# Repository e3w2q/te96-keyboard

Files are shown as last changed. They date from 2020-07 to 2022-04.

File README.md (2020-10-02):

# te96




Expandable keyboard PCB with a smaller pitch.

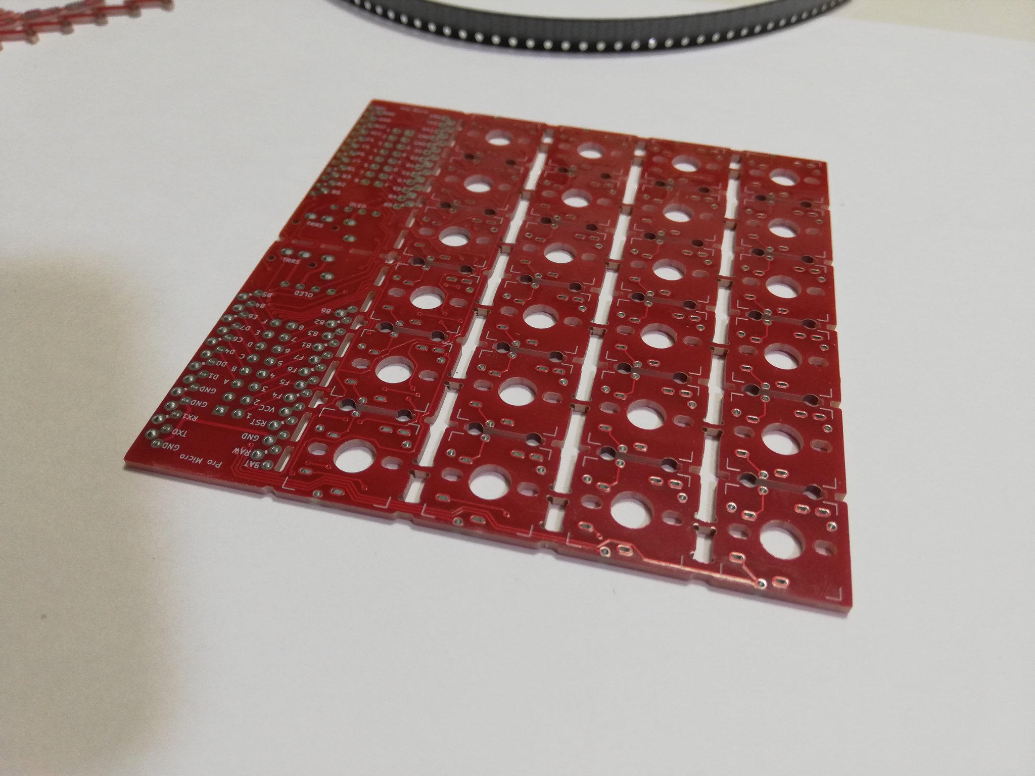
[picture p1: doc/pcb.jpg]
main image


## What is the te96?

The te96 is a keyboard board that can be assembled and expanded in the same way as the [SU120](https://github.com/e3w2q/su120-keyboard), but with a smaller pitch.

I designed the PCB to make it easy to trial and error a smaller pitch keyboard layout.

You may make Row-Staggered, Column-Staggerd, Ortholinear layouts keyboard.

The "te"(手) is named after the Japanese word for 手助け(help) and 手に馴染む(comfort).

## Why open source?

Anyone interested in keyboard could try the keyboard layout more easily.

## Link

[Hardware data (PCB)](pcb/)

[PCBの入手方法](doc/common/pcb_order_guide_jp.md)

[Firmware](https://github.com/e3w2q/qmk_firmware/tree/e3w2q/keyboards/e3w2q/te96)

[自由なレイアウトを作成するには](doc/custom_layout/readme_jp.md)

## Example

### 24 Key Keypad

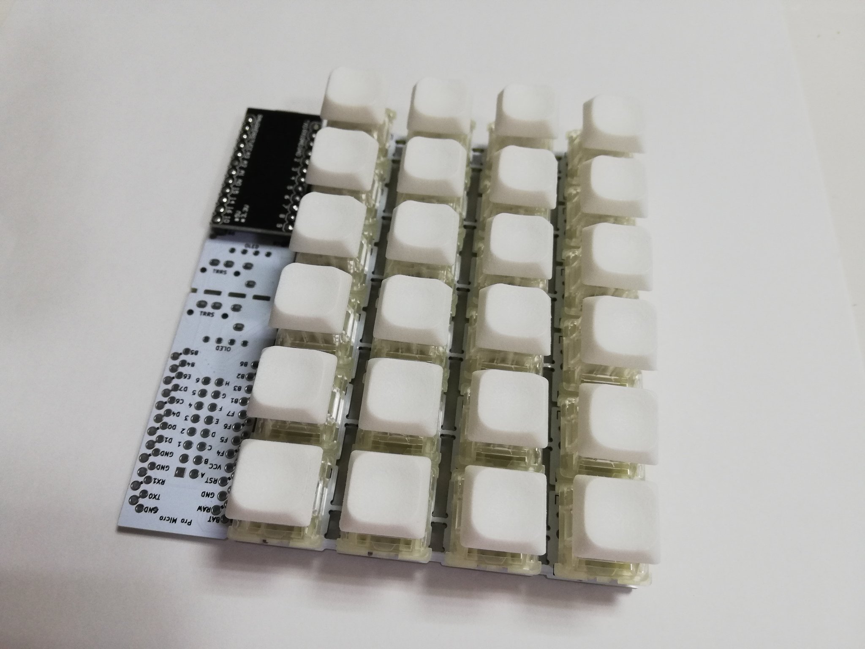
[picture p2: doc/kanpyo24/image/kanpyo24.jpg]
kanpyo24


[ビルドガイド](doc/kanpyo24/readme_jp.md)

### Row-Staggered Keyboard

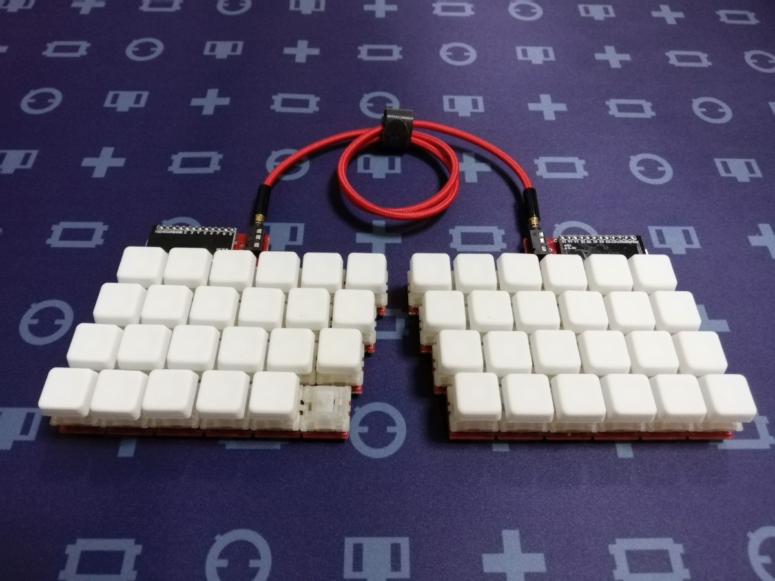
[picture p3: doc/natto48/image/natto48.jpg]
natto48


[ビルドガイド](doc/natto48/readme_jp.md)

### Column-Staggerd Keyboard

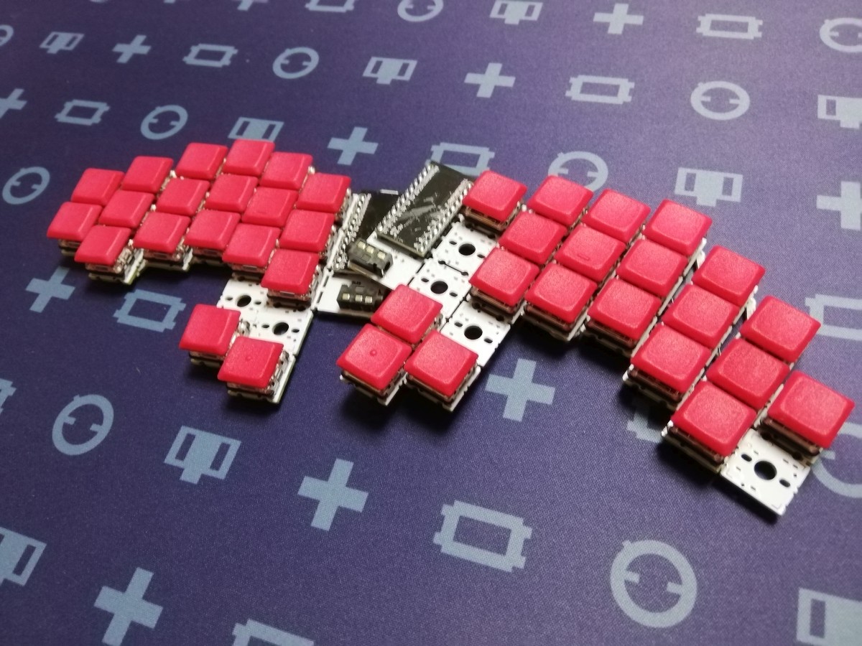
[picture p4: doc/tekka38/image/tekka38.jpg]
tekka38


[ビルドガイド](doc/tekka38/readme_jp.md)

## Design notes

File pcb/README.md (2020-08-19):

# te96 PCB Data

## Schematic
[Schematic PDF](../doc/te96.pdf?raw=true)
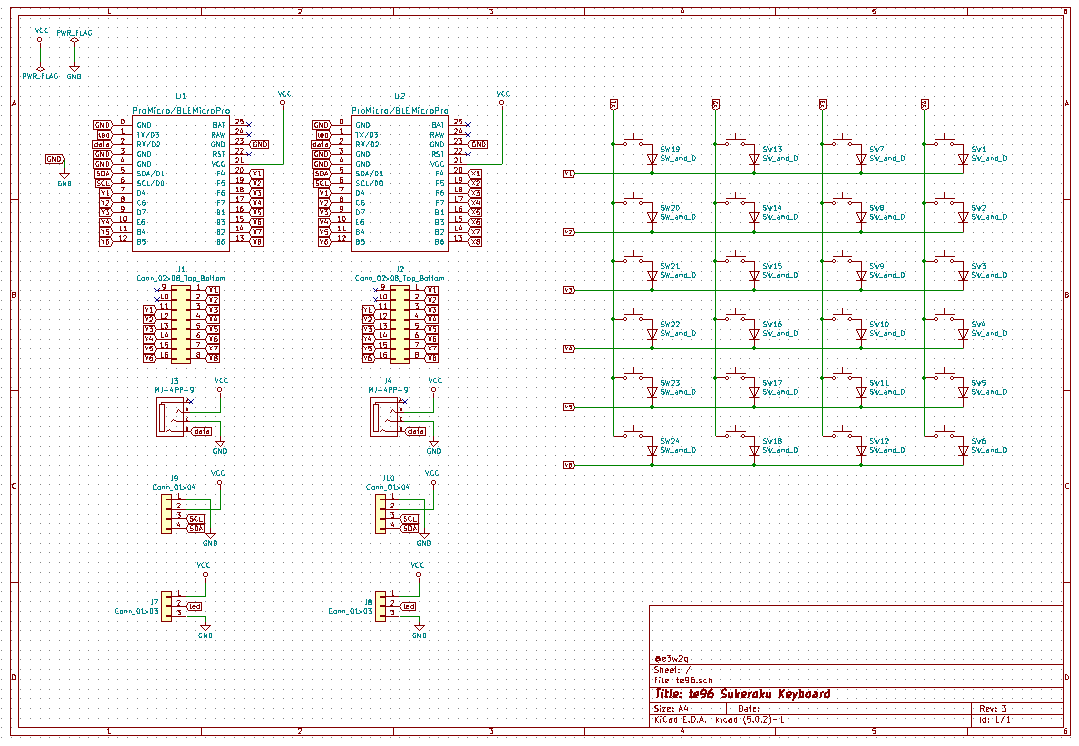
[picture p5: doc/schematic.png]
Schematic


## PCB Layout
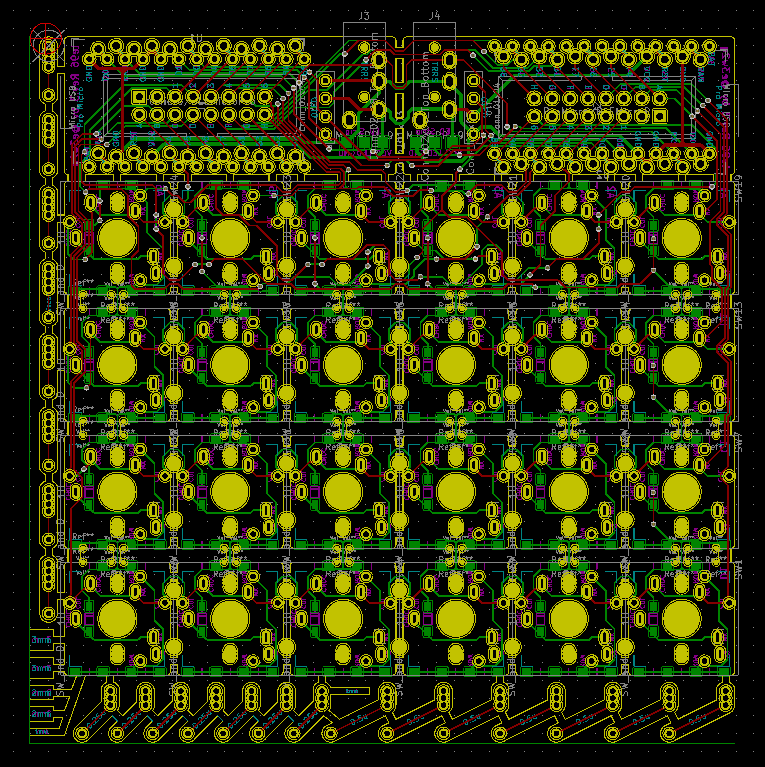
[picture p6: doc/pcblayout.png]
PCB Layout


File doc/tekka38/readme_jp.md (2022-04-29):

# Column-Staggered Keyboard

tekka38

縦16mmキーピッチ、横は16～18mmキーピッチのColumn-Staggerdキーボード（縦方向にズレたキーボード）の作例です。

<!-- TOC -->

- [Column-Staggered Keyboard](#column-staggered-keyboard)
    - [必要なパーツ](#必要なパーツ)
    - [使用する道具、消耗品](#使用する道具消耗品)
    - [ビルドガイド](#ビルドガイド)
        - [Pro Microのもげ防止加工](#pro-microのもげ防止加工)
        - [基板のカット](#基板のカット)
        - [基板側面のヤスリがけ](#基板側面のヤスリがけ)
        - [はんだ付けのイメージトレーニング](#はんだ付けのイメージトレーニング)
        - [カットした基板の結合](#カットした基板の結合)
        - [隣り合う場所の配線](#隣り合う場所の配線)
        - [ダイオードの取り付け](#ダイオードの取り付け)
        - [Pro Microの取り付け（Pro Micro付属のピンヘッダを使う場合）](#pro-microの取り付けpro-micro付属のピンヘッダを使う場合)
        - [Pro Microの取り付け（コンスルーピンヘッダを使う場合）](#pro-microの取り付けコンスルーピンヘッダを使う場合)
        - [TRRSコネクタの取り付け](#trrsコネクタの取り付け)
        - [キースイッチの取り付け](#キースイッチの取り付け)
        - [離れている場所の配線](#離れている場所の配線)
        - [キーキャップの取り付け](#キーキャップの取り付け)
        - [ゴム足の取り付け](#ゴム足の取り付け)
        - [ファームウェアの書き込み](#ファームウェアの書き込み)
    - [トラブルシューティング](#トラブルシューティング)

<!-- /TOC -->

## 必要なパーツ

[te96 パーツリスト](../common/bom_list_jp.md)をご覧ください。

te96基板は3枚使用します。

## 使用する道具、消耗品

[使用する道具、消耗品](../common/tool_guide_jp.md)におすすめの道具類、注意事項等をまとめましたのでご覧ください。

## ビルドガイド

### Pro Microのもげ防止加工

Pro Microにエポキシ接着剤を盛って、簡単にはもげないようにします。

参考1:[ProMicroのモゲ防止ついでにQMK_Firmwareを書き込む - Qiita](https://qiita.com/hdbx/items/2f3e4ddfcadda2a5578e)
参考2:[もげ予防 - Self-Made Keyboards in Japan](https://scrapbox.io/self-made-kbds-ja/%E3%82%82%E3%81%92%E4%BA%88%E9%98%B2)

エポキシ接着剤の2液を混ぜます。

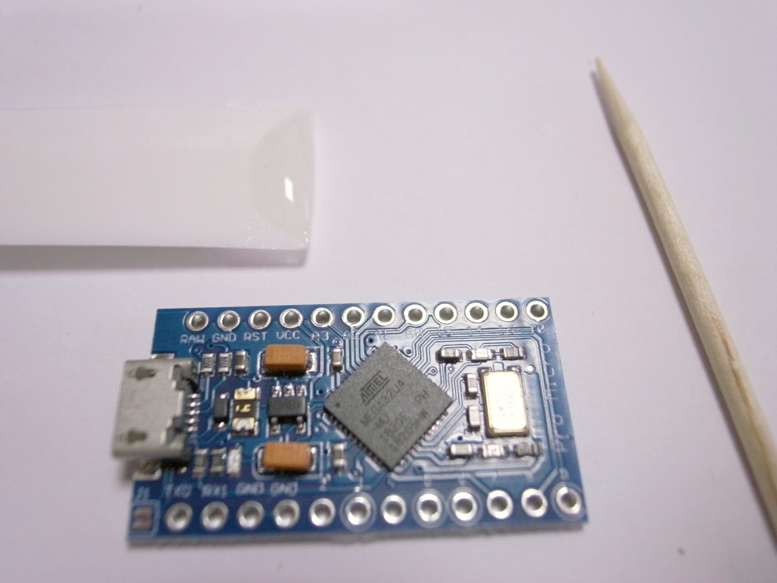
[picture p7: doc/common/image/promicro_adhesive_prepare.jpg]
adhesive_prepare


接着剤を付け始める前にMicro USBコネクタを横から見てください。側面に穴が開いています。この穴に接着剤が入ると端子が入らなくなったり、入りにくくなったりします。

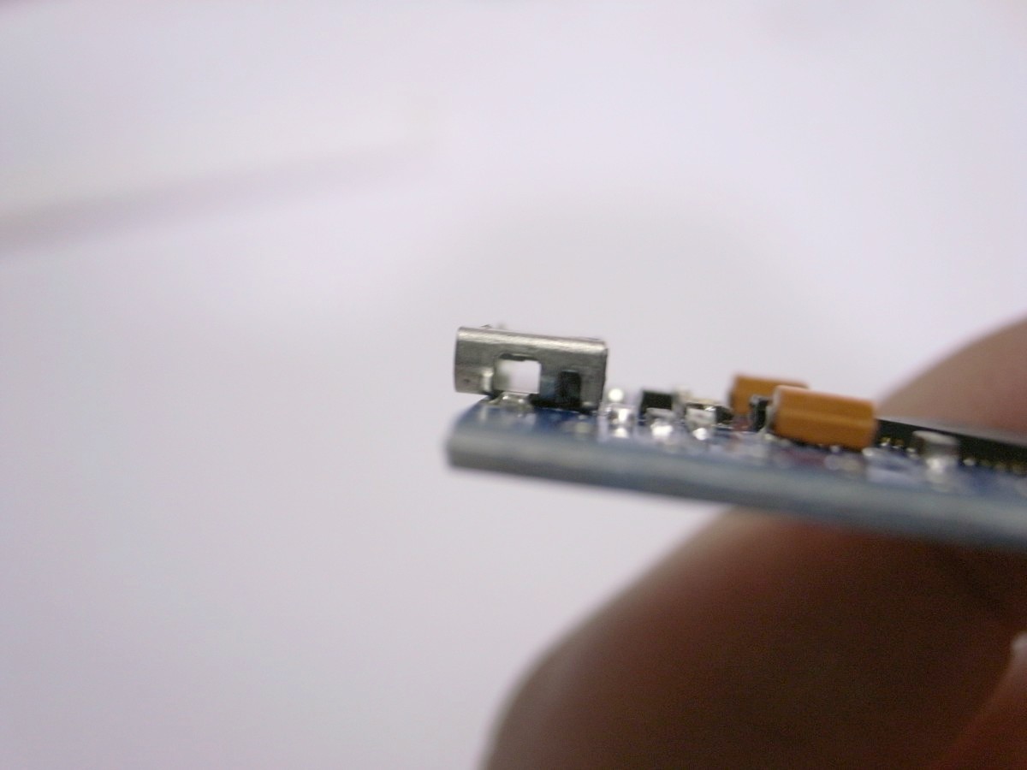
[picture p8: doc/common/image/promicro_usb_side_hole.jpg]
usb_side_hole


この穴を避けて、つまようじなどで接着剤を盛っていきます。

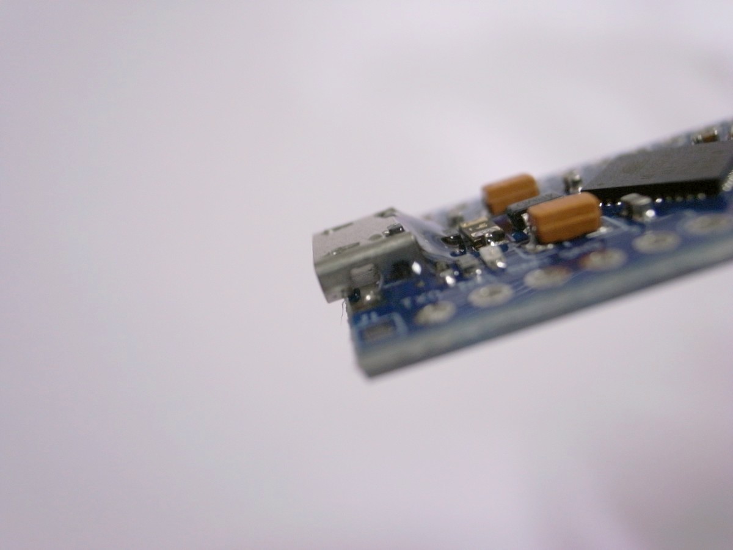
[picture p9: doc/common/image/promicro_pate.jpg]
promicro_pate


乾くまで置いておきます。

### 基板のカット

下の図のように、ニッパーで切っていきます。ニッパーで表裏に切れ目を入れてから手で折り割ってください。

Pro Micro部は左右のどちらを残しても動きます。分割キーボードでPro Micro部を左右対称にしたい場合は注意してください。

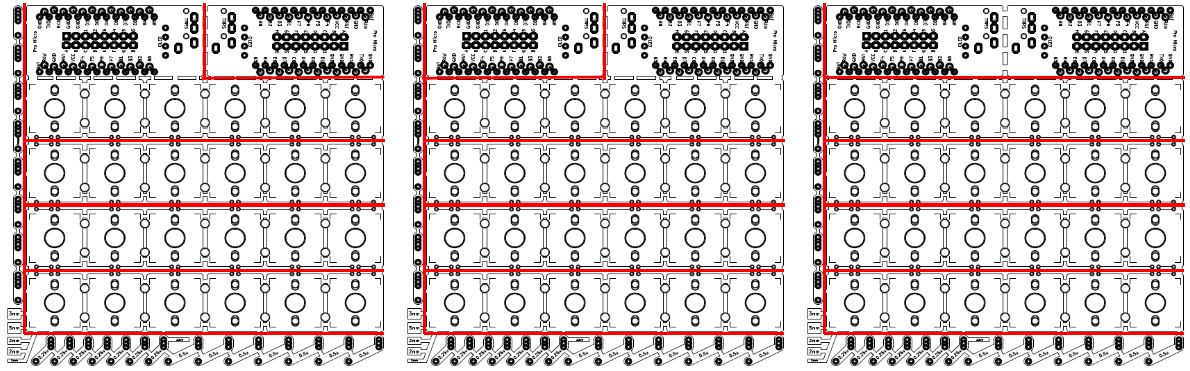
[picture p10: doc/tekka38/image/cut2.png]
cut2


基板を並べてみて、自分の手に合ったちょうどよいズレ方を探します。縦方向のズレは

- ズレなし
- 0.25Uズレ
- 0.5Uズレ

を選べます。

各列の隙間は、

- 隙間なし（16mmキーピッチ）
- 1mm隙間あり（17mmキーピッチ）
- 2mm隙間あり（18mmキーピッチ）

を選べます。

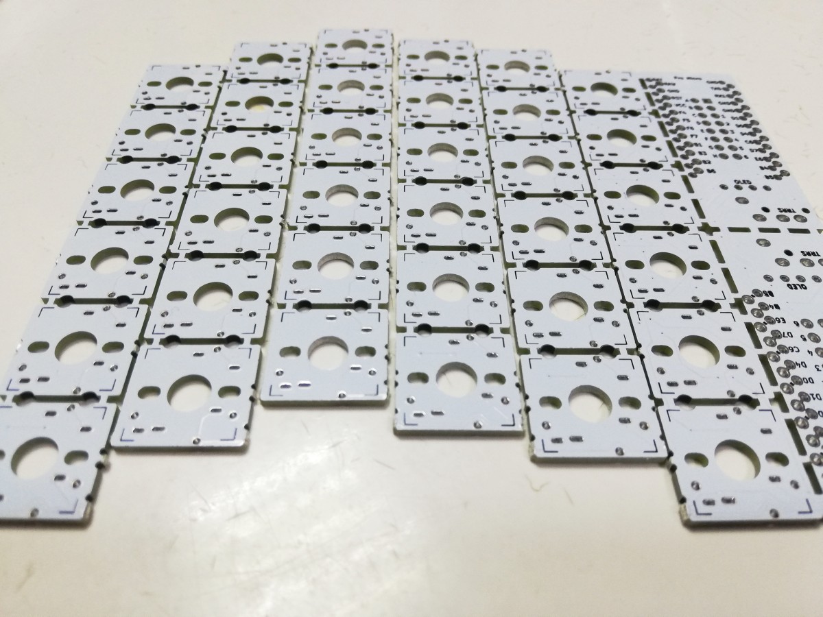
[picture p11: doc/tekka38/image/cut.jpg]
cut


使わない部分をカットします。

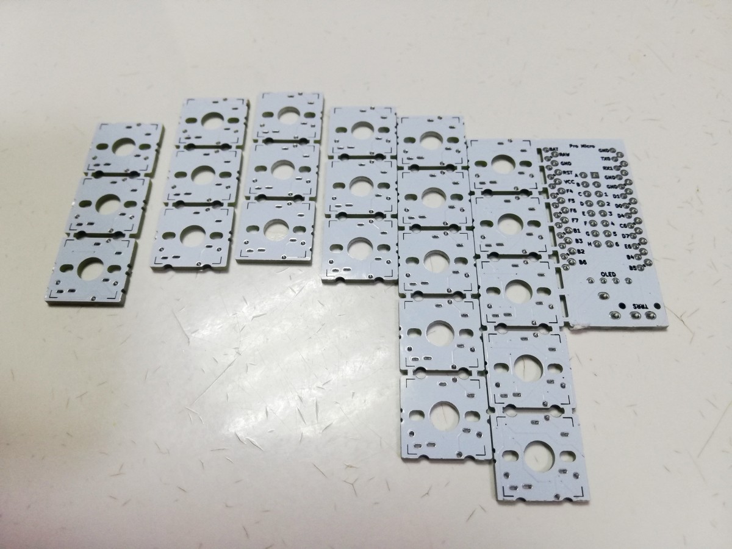
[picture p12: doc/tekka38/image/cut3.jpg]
cut3


### 基板側面のヤスリがけ

机に紙ヤスリを置き、その上で基板のバリがある側面をヤスリがけします。粗目だけでも結構きれいになります。お好みで細目までかけてもよいです。

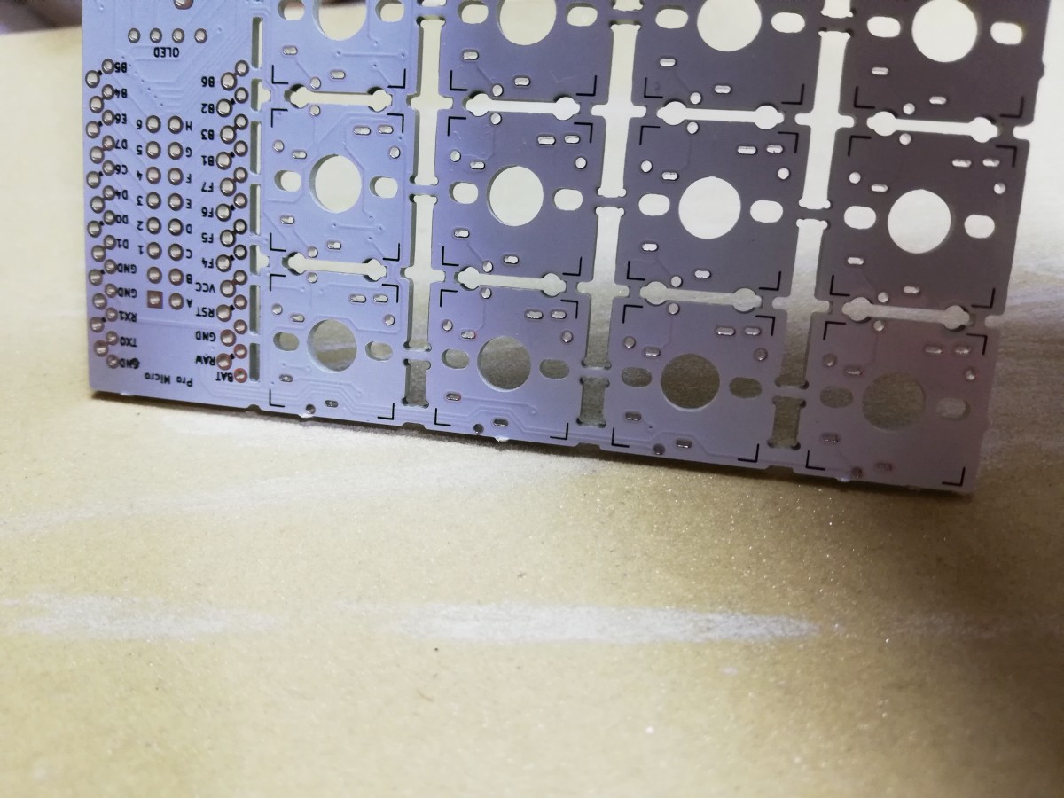
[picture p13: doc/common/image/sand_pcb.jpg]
sand_pcb


### はんだ付けのイメージトレーニング

はんだ付けに慣れている方は次の項に進んでください。

全くはんだ付けをしたことがなかったり、数年ぶりにはんだ付けをする場合は、以下の動画が参考になります。

- [はんだ付けの詳細.m2p - YouTube](https://www.youtube.com/watch?v=ZA-ehWjRfYM)

- [チップ抵抗のはんだ付けと、はんだ量の調整（体験用基板を使用） - YouTube](https://www.youtube.com/watch?v=vqKKElJ1vw0)

- [基礎からわかる！自キ入門講座 第8回「自作キーボードのつくりかた #2」 - YouTube](https://www.youtube.com/watch?v=LOC53FeU-QM&t=999)

### カットした基板の結合

まず**カットした基板を表側にして完成形に並べてからマスキングテープで仮止めしておいてください**。これをせずに進めて、表に向けたときに想定したずらし方と逆になっていたことがありました。

基板を裏返し、ビスケットで結合していきます。ビスケットは3種類あります。下の写真の左から

- 0.5uずらして接続する用
- 0.25uずらして接続する用
- ずらさずに接続する用

です。

縦に連なっている穴は下から

- 16mmキーピッチ用
- 17mmキーピッチ用
- 18mmキーピッチ用
- 19mmキーピッチ用（ずらさずに接続する用のみ）

です。

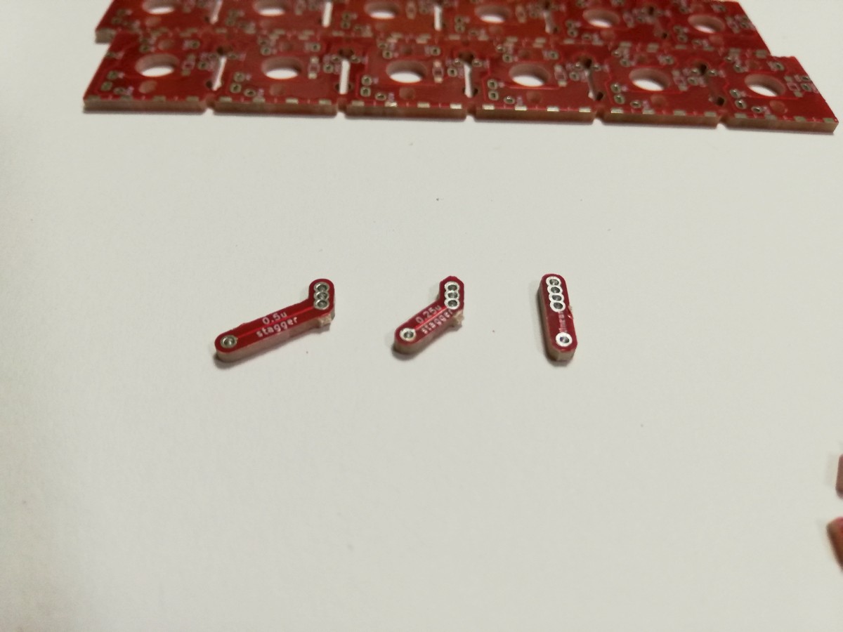
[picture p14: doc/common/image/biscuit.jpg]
biscuit


基板を裏返してビスケットで接続していきます。ビスケットの数が限られているので、下の写真のように、基本的には各列2個のビスケットを使って接続します。ビスケットの数に余裕があればもっと使っても構いません。

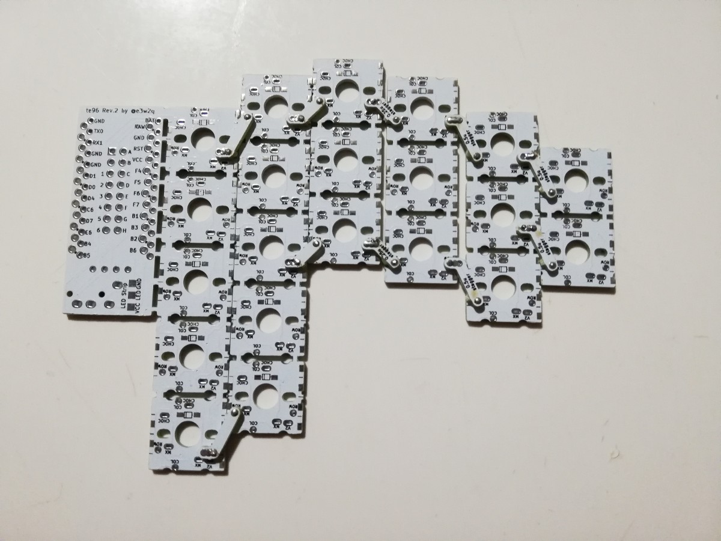
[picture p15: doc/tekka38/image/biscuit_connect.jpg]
biscuit_connect


基板の`ROW`と書かれている穴にビスケットを重ねて、ビンヘッダを差し込みます。

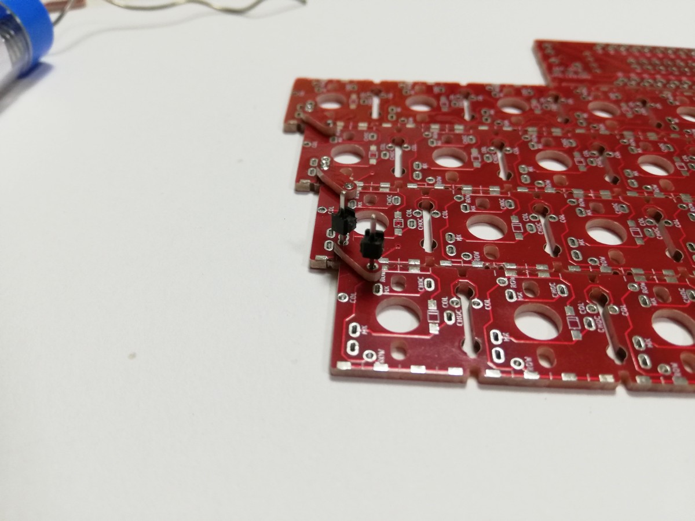
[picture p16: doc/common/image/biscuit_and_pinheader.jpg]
biscuit_and_pinheader


ビスケットからはみ出しているピンヘッダをニッパーでカットして、穴の上からハンダを流し込みます。

16mmキーピッチで接続する場合は基板と基板をくっつけてビスケットで接続すればよいのですが、1mm間隔を空けて17mmキーピッチにしたい場合は、基板に付属の1mmスペーサーをニッパーで切って基板の間に挟んで間隔を空けてください。

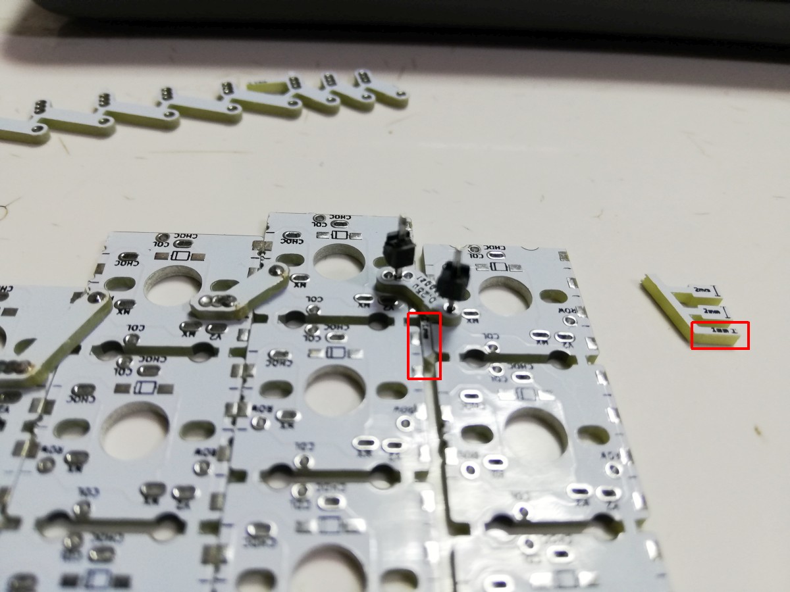
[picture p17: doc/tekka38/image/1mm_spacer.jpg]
1mm_spacer


2mm間隔を空けて18mmキーピッチとしたい場合、同様に基板に付属の2mmスペーサーを使ってください。

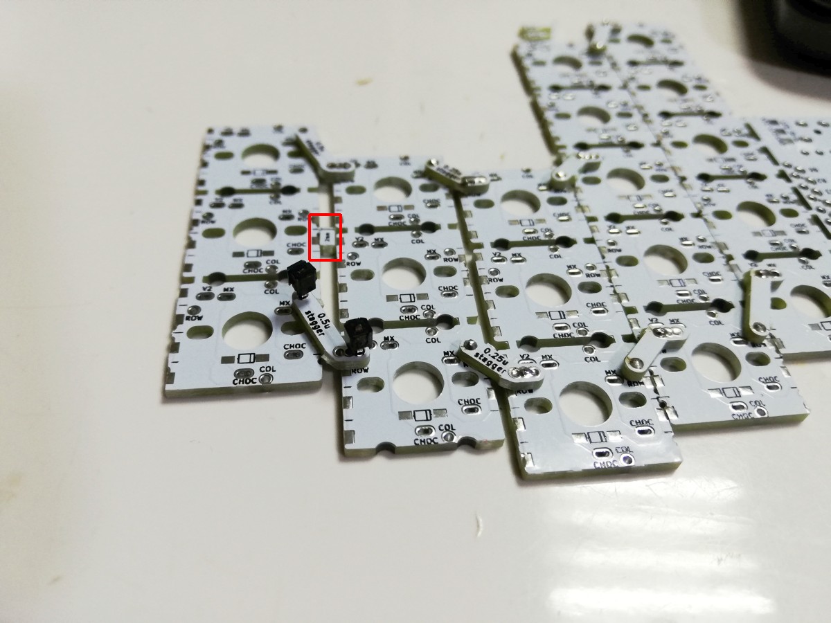
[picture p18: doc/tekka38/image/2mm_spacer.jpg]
2mm_spacer


上下で間隔を変えて、扇形のようにすることも可能です。

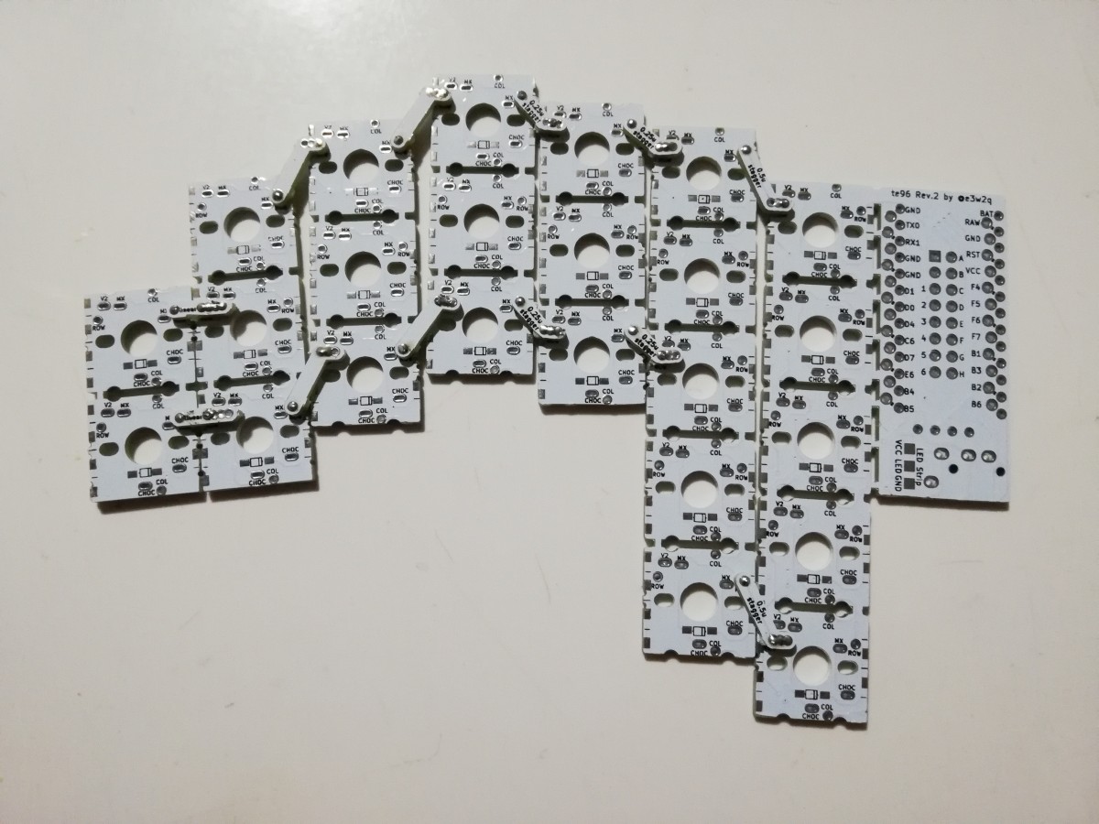
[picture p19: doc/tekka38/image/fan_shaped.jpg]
fan_shaped


### 隣り合う場所の配線

下の写真の赤線のように、ビスケットで接続していない部分の`ROW`と`ROW`をハンダめっき線またはダイオードの切れ端などで配線し、ハンダ付けします。

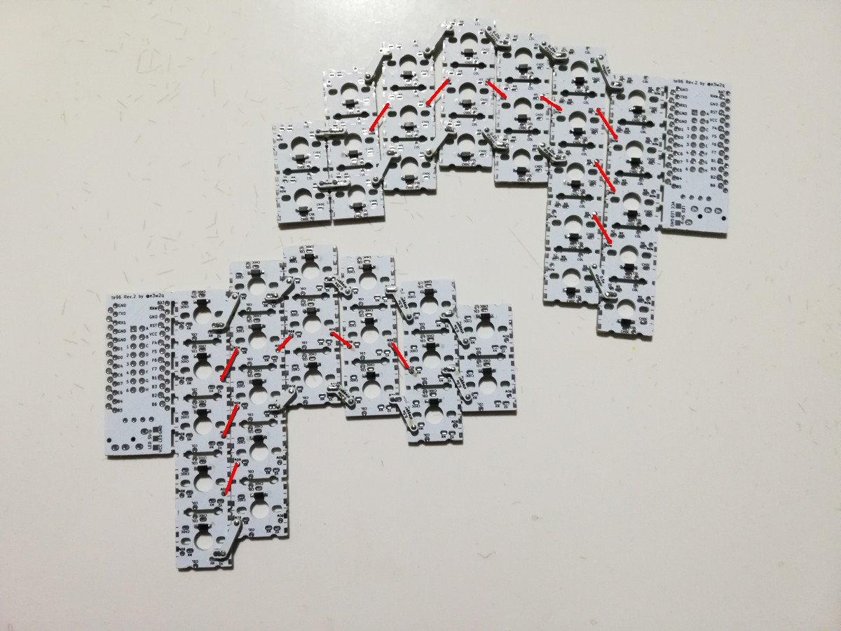
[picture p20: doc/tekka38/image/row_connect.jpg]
row_connect


### ダイオードの取り付け

基板裏側にキースイッチの数だけダイオードを取り付けます。

キースイッチの枠が描いてあるほうが基板の表で、ダイオードの印が描いてあるほうが裏です。

まず片方のパッド上にはんだを溶かして盛ります。

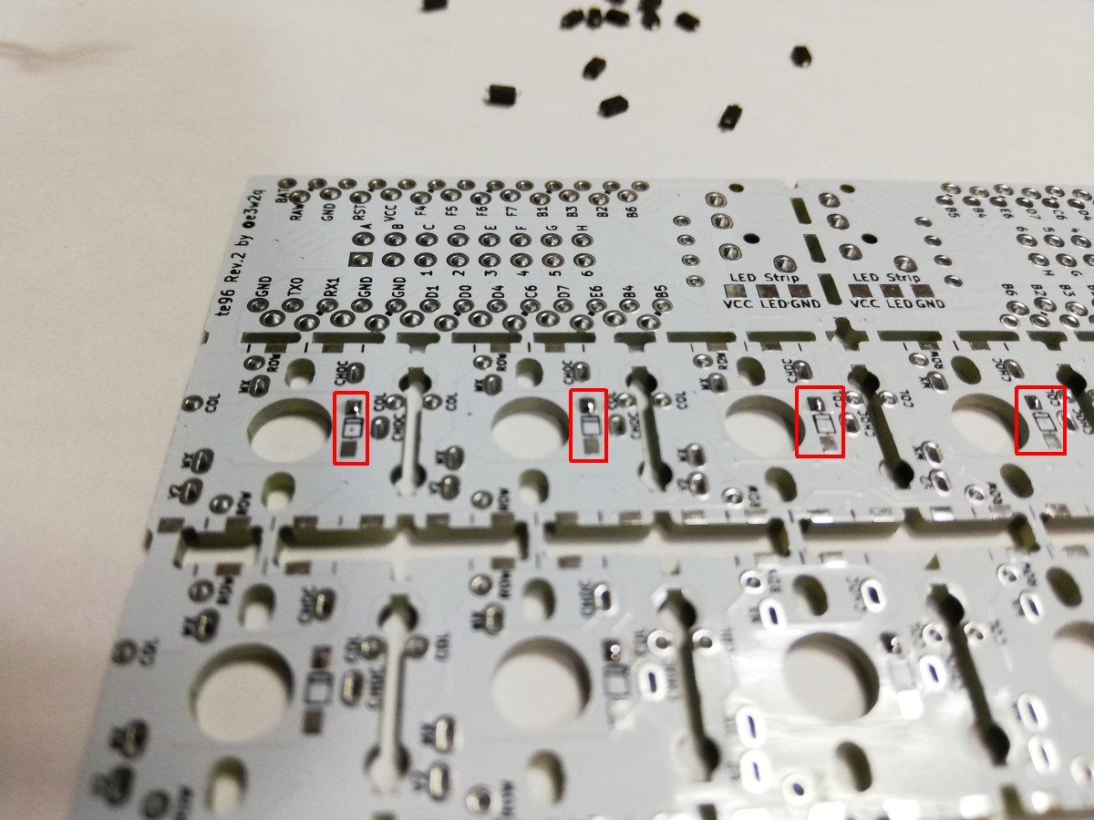
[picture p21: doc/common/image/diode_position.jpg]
diode_position


ダイオードをピンセットでつまみ、基板のシルク印刷の二重線と、表面実装ダイオードの二重線の向きを合わせて、パッドに置きます。

先程パッドに盛ったはんだを溶かしてダイオードの片側をはんだ付けします。

うまくいかない場合は以下の動画をご覧ください。

- [チップ抵抗のはんだ付けと、はんだ量の調整（体験用基板を使用） - YouTube](https://www.youtube.com/watch?v=vqKKElJ1vw0)

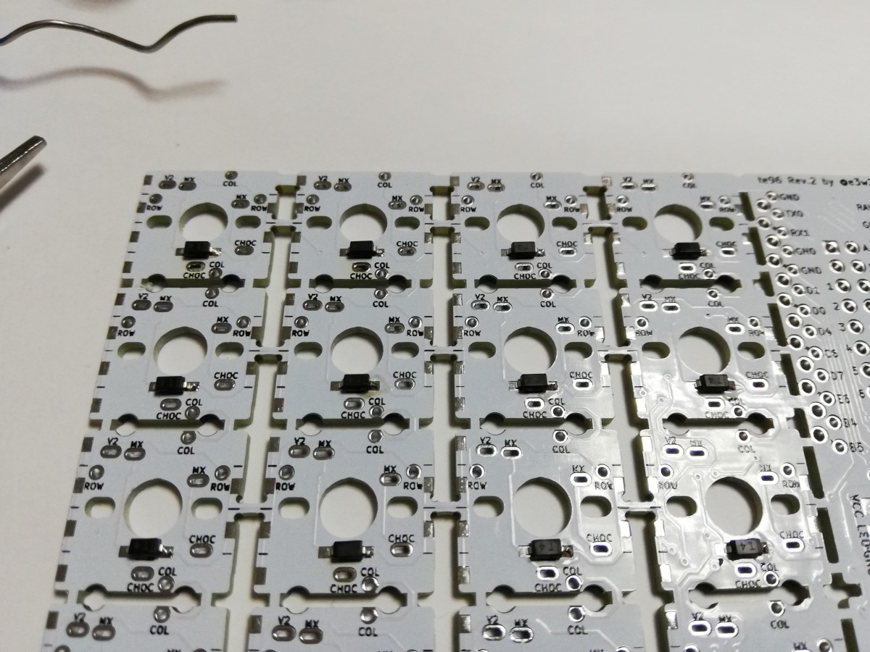
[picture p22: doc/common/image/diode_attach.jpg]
diode_attach


表面実装ダイオードのはんだ付けをしていない側をはんだ付けします。

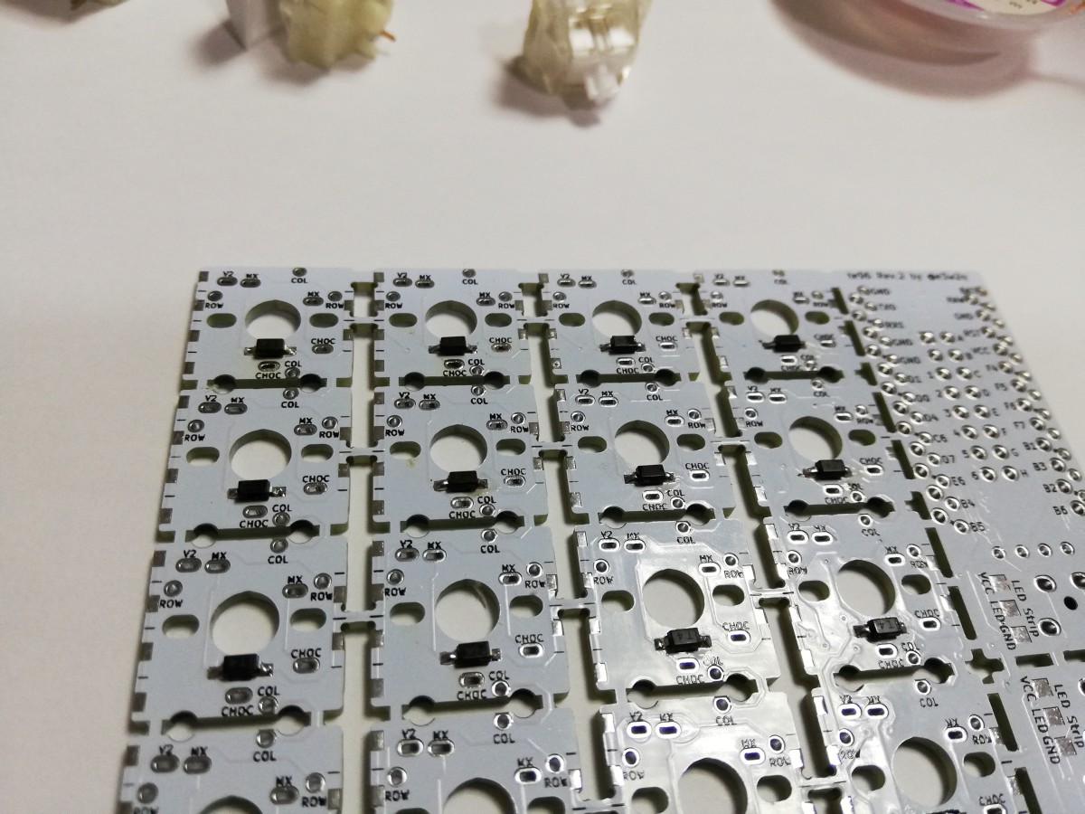
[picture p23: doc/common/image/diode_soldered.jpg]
diode_soldered


### Pro Microの取り付け（Pro Micro付属のピンヘッダを使う場合）

**基板表側**のPro Micro設置部分のジグザグスルーホールに、Pro Microに付属している12ピンのピンヘッダの短い側を根本まで差し込みます。

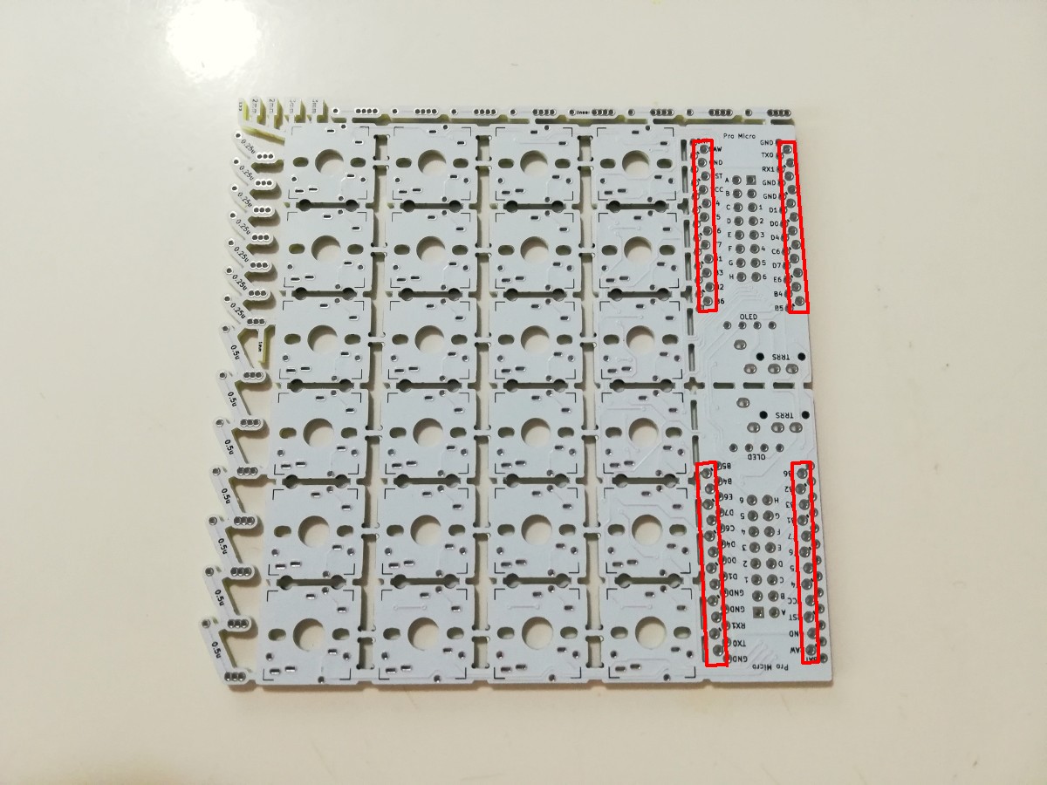
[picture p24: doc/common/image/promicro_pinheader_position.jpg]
promicro_pinheader_position


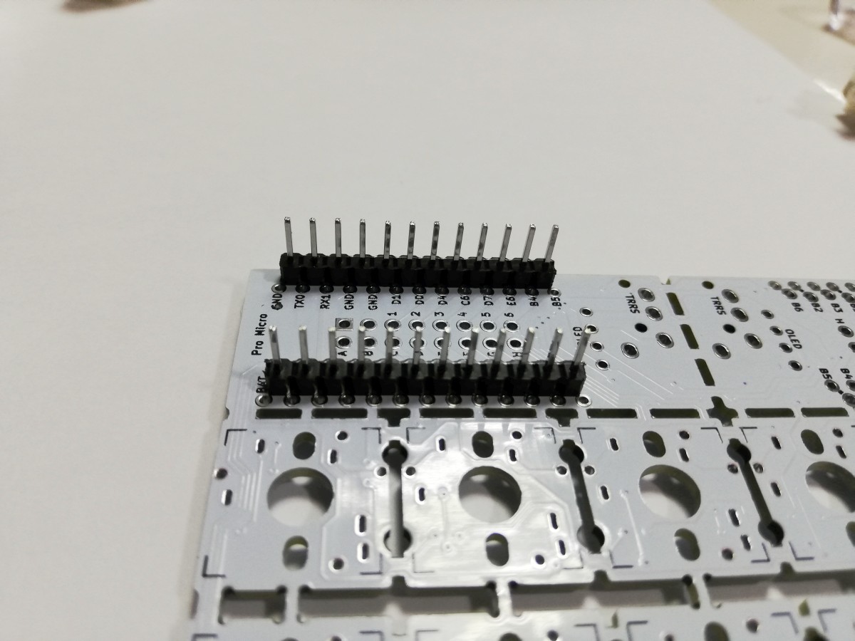
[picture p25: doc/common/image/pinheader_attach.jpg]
pinheader_attach


スルーホールがジグザグになっているので、少し入れにくくなっています。ゆっくり押し込んでください。

ピンヘッダにPro Microを差し込みます。**Pro Microの裏面（平らなほう）が上になるように、またマイクロUSBが基板端になるように**します。

**向きを間違えるとリカバリーが大変です。表裏、左右をよく確認してください。**

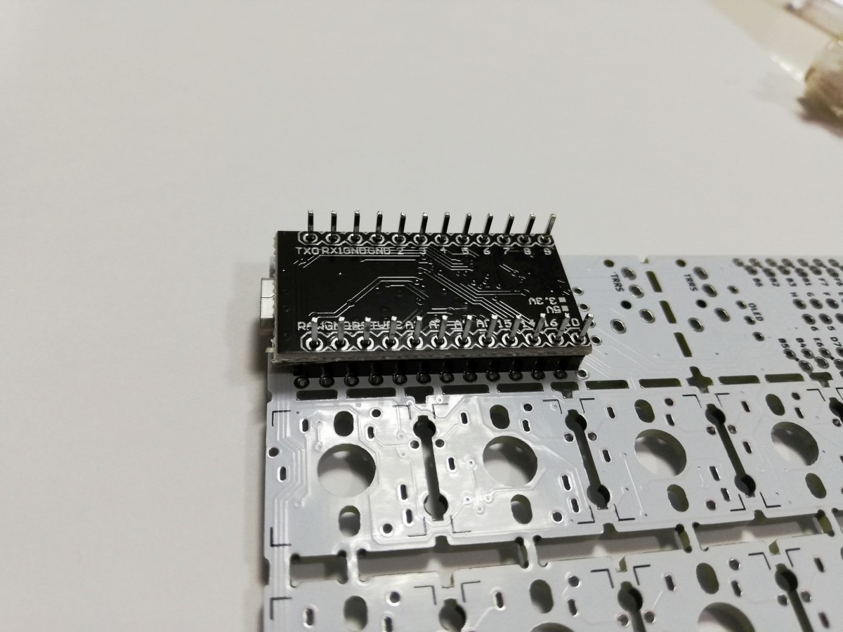
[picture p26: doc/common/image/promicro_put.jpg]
promicro_put


ニッパーでピンヘッダの足のはみ出している部分を切ってから、Pro Microとピンヘッダをハンダ付けします。まず四隅をハンダ付けし、横から見てピンヘッダとの間に隙間があれば押さえながらハンダを温めて浮かないようにします。そのあと、順番に全てハンダ付けします。

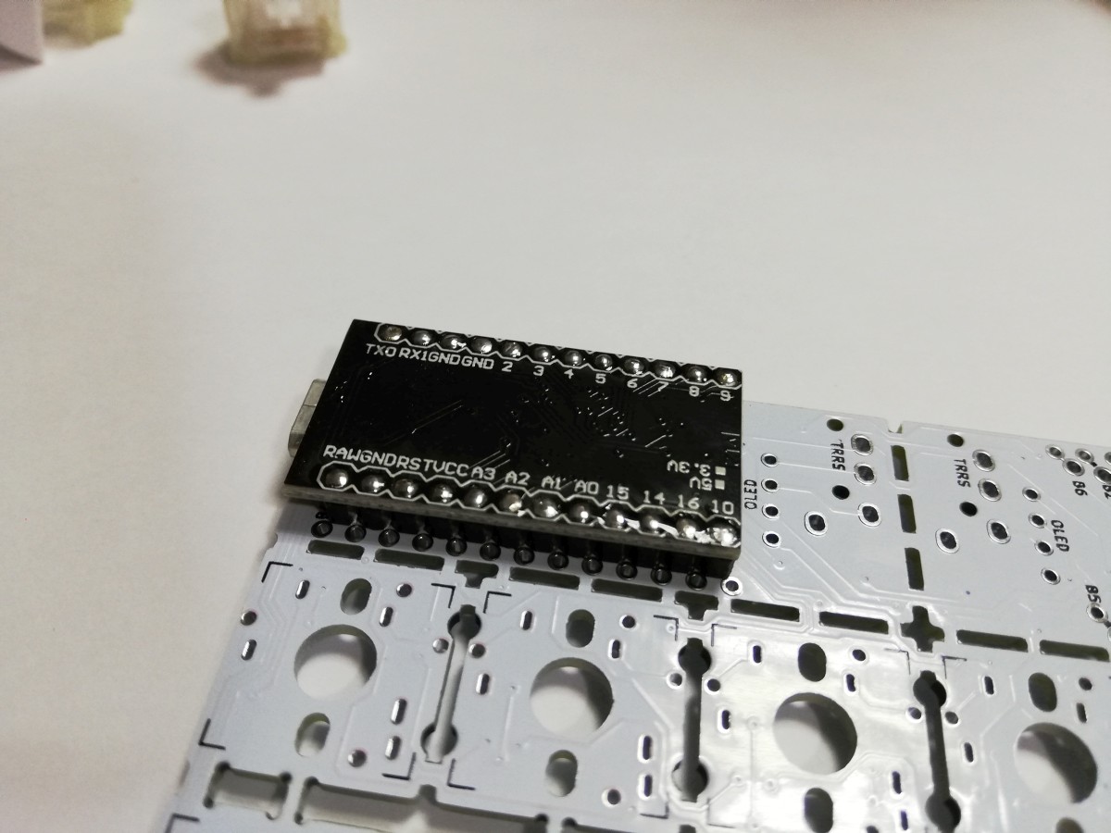
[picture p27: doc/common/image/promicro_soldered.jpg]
promicro_soldered


基板とピンヘッダはジグザグのスルーホールで接触しているため、ハンダ付けはしなくても経験的には大丈夫ですが、接触不良が気になる場合ははんだ付けしてください。

| | 基板とピンヘッダをはんだ付けしない | 基板とピンヘッダをはんだ付けする |
| --- | --- | --- |
| メリット | はんだ付け箇所が減る<br />Pro MicroのMicro USBがモゲたときに交換できる | キーが反応しないとき、接触不良をまず疑うべき箇所が減らせる |
| デメリット | 接触不良により行単位、列単位でキーが反応しない場合がある | はんだ付け箇所が増える<br />Pro MicroのMicro USBがモゲたときに交換が難しい |

### Pro Microの取り付け（コンスルーピンヘッダを使う場合）

**基板表側**のPro Micro設置部分のジグザグではないスルーホール（一番外側の穴を除く）に、別途調達したコンスルーピンヘッダを根本まで差し込みます。

その際、

- コンスルーピンヘッダの金色の窓が遠い側を基板側とし、金色の窓が近い側をProMicro側とする
- 金色の窓の向きを揃える

ようにしてください。

参考: [Helixベータ ビルドガイド](https://github.com/MakotoKurauchi/helix/blob/master/Doc/buildguide_jp.md#pro-micro)

ピンヘッダにPro Microを差し込みます。**Pro Microの裏面（平らなほう）が上になるように、またマイクロUSBが基板端になるように**します。

**向きを間違えるとリカバリーが大変です。表裏、左右をよく確認してください。**

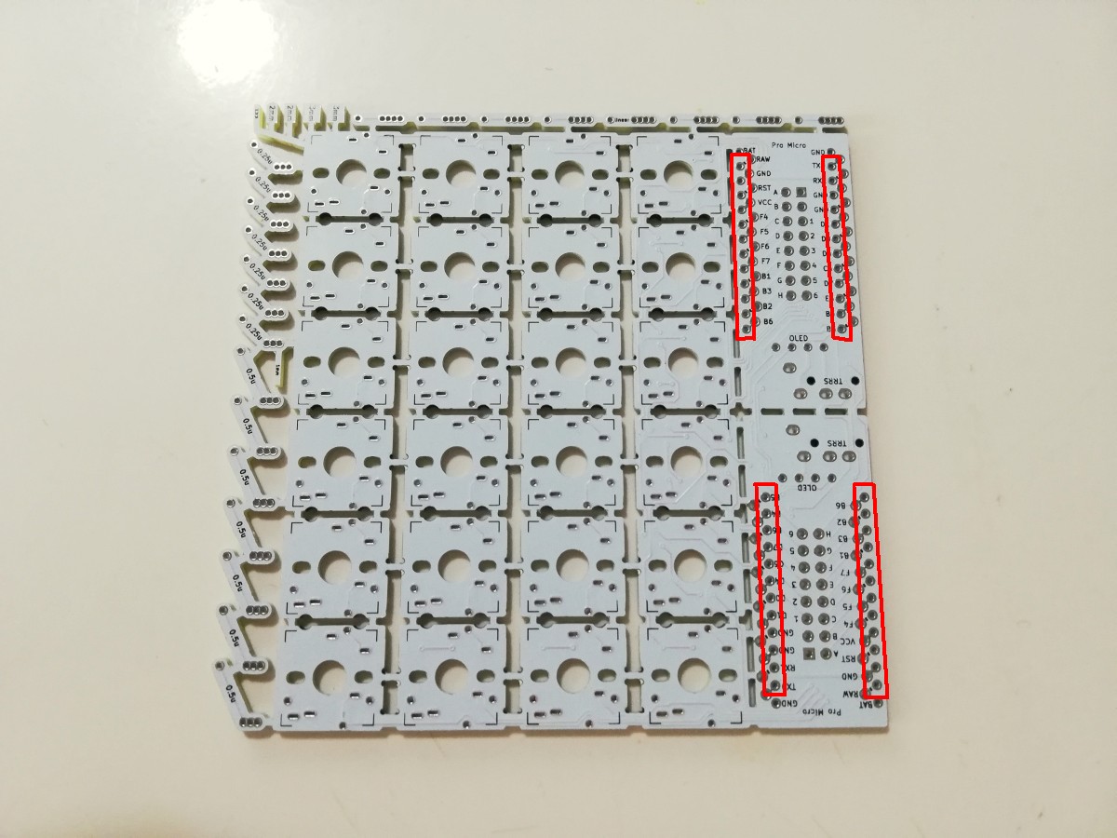
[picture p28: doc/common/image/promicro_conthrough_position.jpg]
promicro_conthrough_position


Pro Microとコンスルーピンヘッダをハンダ付けします。まず四隅をハンダ付けし、横から見てコンスルーピンヘッダとの間に隙間があれば押さえながらハンダを温めて浮かないようにします。そのあと、順番に全てハンダ付けします。

基板とコンスルーピンヘッダは接触しているため、ハンダ付けしません。

### TRRSコネクタの取り付け

表側から差し込みます。まず裏側の一箇所をハンダ付けし、コネクタが基板から浮いていないか確認します。もし浮いていれば、コネクタを押さえながらハンダを温めて溶かし直してください。

trrs_jack

### キースイッチの取り付け

表側から差し込みます。トッププレート無しでもキースイッチのガタつきがないよう、穴のサイズを小さめにしてあります。キースイッチの足が曲がっている場合はまっすぐにしてから差し込んでください。

裏返してハンダ付けします。

switch_attach

### 離れている場所の配線

切り離した基板の`COL`をPro Microと接続していきます。

1列目はPro Microと接続したままなので配線不要です。

2列目の`COL`のどれかと、Pro Micro中央の`B`と書いてあるスルーホールを被覆銅線またはポリウレタン銅線で繋ぎます。

Pro Micro側の配線をする際、配線をスルーホールに押し込むとPro Microとショートする可能性があるので注意してください。

3行目の`COL`のどれか（黄緑色の丸のどれか）と、Pro Micro中央の`C`と書いてあるスルーホール（黄緑色の四角）を被覆銅線またはポリウレタン銅線で繋ぎます。

4行目の`COL`のどれか（オレンジ色の丸のどれか）と、Pro Micro中央の`D`と書いてあるスルーホール（オレンジ色の四角）を被覆銅線またはポリウレタン銅線で繋ぎます。

残りのすべての列も同様に`E`、`F`、`G`…に接続してください。

col_connect

### キーキャップの取り付け

キースイッチにキーキャップをはめます。

tekka38

### ゴム足の取り付け

ゴム足を裏面に取り付けます。ソケットやキースイッチに接触する場合はハサミで切ってから取り付けます。

rubber_foot

試打してみて、基板のたわみが気になればゴム足を増やしてください。

### ファームウェアの書き込み

以下のリンク先を参考にして、QMK Firmwareのビルド環境を用意します。

- Windows
  - [QMKビルド環境の構築(Windows Msys2編)](https://gist.github.com/e3w2q/4bc86e531d1c893d3d13af3e9895a94a)
- macOS
  - [セットアップ - QMK Firmware](https://docs.qmk.fm/#/ja/newbs_getting_started?id=macos)
- Linux
  - [セットアップ - QMK Firmware](https://docs.qmk.fm/#/ja/newbs_getting_started?id=linux)

構築中、

```
qmk setup
```

と入力する代わりに

```
qmk setup e3w2q/qmk_firmware --branch e3w2q
```

と入力してください。

または、`qmk setup`した後に、`C:\Users\USER_NAME\qmk_firmware\keyboards`配下に[https://github.com/e3w2q/qmk_firmware/tree/e3w2q/keyboards/e3w2q](https://github.com/e3w2q/qmk_firmware/tree/e3w2q/keyboards/e3w2q)以下をコピーしてもよいです。

用意されたキーマップを書き込むには以下を実行します。

注：完成写真の左手側の配列で両手分作った場合のキーマップとなっています。

```
qmk flash -kb e3w2q/te96/rev1_inverted -km tekka38
```

`Detecting USB port, reset your controller now...`と表示されたらPro Microの`GND`と`RST`をピンセットやクリップなどで短絡させると書き込みが始まります。

promicro_reset

[QMK Configuratorのテストモード](https://config.qmk.fm/#/test)でキー入力が行えるかテストしてください。

## トラブルシューティング

- 特定のキーが反応しない
  - キースイッチのハンダ付けが甘い場合があります。キースイッチを押すかわりに、キースイッチの裏面のハンダ2箇所をピンセットでショートさせてみて、入力されるか確認してください。入力される場合は、ハンダ付けし直してください。
- 行、列単位でキーが反応しない
  - Pro Microの足と基板のZigzag穴とがうまく導通していない可能性があります。該当する行または列のPro Microの足を基板のスルーホールの壁に押し付けた状態でキー入力ができるか試してください。この状態でキー入力ができる場合は、きちんと導通するようにPro Microの足が基板の穴の壁に接するようにちょっと曲げてから差し込んでみてください。はんだ付けしてしまうのもよいです。

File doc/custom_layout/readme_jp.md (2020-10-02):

[English](index.md) / [日本語](index_jp.md)

# te96で自由なレイアウトを作成するには

top

te96では基板間をビスケットで接続することである程度自由なキー配置が可能です。

<!-- TOC -->

- [te96で自由なレイアウトを作成するには](#te96で自由なレイアウトを作成するには)
    - [基板の説明](#基板の説明)
    - [配置できるキー数の上限](#配置できるキー数の上限)
    - [カットした基板の接続](#カットした基板の接続)
    - [ビスケット](#ビスケット)
    - [作成可能なキーレイアウト](#作成可能なキーレイアウト)
        - [Ortholinear（オーソリニア）、格子配列](#ortholinearオーソリニア格子配列)
        - [Row-Staggered（ロウスタッガード）](#row-staggeredロウスタッガード)
        - [Column-Staggered（カラムスタッガード）](#column-staggeredカラムスタッガード)
    - [キーマトリクスの配線](#キーマトリクスの配線)
        - [ROW間の配線](#row間の配線)
        - [ROWとPro Microとの配線](#rowとpro-microとの配線)
        - [COL間の配線](#col間の配線)
        - [COLとPro Microとの配線](#colとpro-microとの配線)
    - [ファームウェア](#ファームウェア)
        - [左サイドにPro Microがある向きで使用する場合](#左サイドにpro-microがある向きで使用する場合)
        - [上側にPro Microがある向きで使用する場合](#上側にpro-microがある向きで使用する場合)
        - [Pro Microが向かい合う形で使用する場合](#pro-microが向かい合う形で使用する場合)
        - [テスト用のキーマップ](#テスト用のキーマップ)
        - [ファームウェアの書き込み](#ファームウェアの書き込み)

<!-- /TOC -->

## 基板の説明

基板1枚に縦6行、横4列、計24キーが配置されています。

基板の表側から見て、横は左からA B C D、縦は上から1 2 3 4 5 6となります。エクセルの番地と同じ考え方です。

1pcb

excel

## 配置できるキー数の上限

Pro Micro1つにつき横方向に4列まで追加して最大6行8列=48キーまで配置できます。

デフォルトファームウェアでは縦方向に拡張することはできません。

2pcb

2つのPro MicroをTRRSケーブルで接続することにより、片側48キー、合計96キーの分割キーボードとして使えます。

DuplexMatrixとして配線することで、さらに倍の192キーまで利用可能となりますが、ここでは説明を割愛します。

## カットした基板の接続

カットした基板はビスケットで接続します。基板とビスケットはビンヘッダの軸を差し込んで位置を合わせます。

biscuit_and_pinheader

ビスケットからはみ出しているピンヘッダの軸をニッパーでカットし、ハンダを流し込んで固定します。

## ビスケット

カットした基板を繋ぐために使う部品です。

基板の外周に配置されています。小さいパーツなので、飛んでいかないように手を添えてください。

pcb

ビスケットは、キースイッチに干渉しないように、基板の裏側から取り付けます。

staggerと書いてあるビスケットは、Row-Staggered、Column-Staggeredなど、行または列をずらして接続する場合に使います。

0.5u staggerは、キー半個分ずらして接続するときに使います。

0.25u staggerは、キー1/4個分ずらして接続するときに使います。

linearはずらさずに接続するときに使います。

縦に連なっている穴は下から

- 16mmキーピッチ用
- 17mmキーピッチ用
- 18mmキーピッチ用
- 19mmキーピッチ用（linearのみ）

です。

biscuit

キーに干渉しないように、基板の裏側でビスケットを使って接続します。ビスケットの数が限られているので、下の写真のように、基本的には1つの行または列に対し2個のビスケットを使って接続します。ビスケットの数に余裕があればもっと使っても構いません。

biscuit_connect

## 作成可能なキーレイアウト

### Ortholinear（オーソリニア）、格子配列

キーが格子状に並んだ配列です。

kanpyo24

Pro Microを上部とするように組む場合、以下の注意点があります。

- 拡張方向が縦となるので横長のキーボードには採用しにくい。
- 横方向のキーピッチが16mmとなるのに対し、縦方向のデフォルトキーピッチは18mmとなる。一般的に横方向のキーピッチ≧縦方向のキーピッチとなっていたほうが使いやすいとされるので、ちょっと不向きかも。縦方向のキーピッチを詰めて16mmとするなら問題はない。

ortholinear1

Pro Microをサイド側に配置して組むと、横方向に拡張できます。また横方向のキーピッチをデフォルト18mmから、手の大きさに合わせて16～19mmの範囲で変更可能です。

ortholinear2

### Row-Staggered（ロウスタッガード）

一般的なキーボードのように横方向にズレた配列です。

natto48

各行のズレ方は、使うビスケットによって、0.5Uズレ、0.25Uズレ、ズレなしを選択できます。

拡張方向が縦なので、片手あたりの列数は6が最大です。

縦方向のキーピッチを16～18mmの範囲で変更可能ですが、一般的に横方向のキーピッチ≧縦方向のキーピッチとなっていたほうが使いやすいとされるので、16mmを採用するケースが多いかもしれません。

row_staggerd

### Column-Staggered（カラムスタッガード）

自作キーボードでも結構採用されている縦方向にズレた配列です。

tekka38

各列のズレ方は、使うビスケットによって、0.5Uズレ、0.25Uズレ、ズレなしを選択できます。

拡張方向が横なので、片手あたり6行8列まで使用できます。

横方向のキーピッチを16～18mmの範囲で変更可能です。

column_staggerd

## キーマトリクスの配線

### ROW間の配線

ビスケットは配線も兼ねているので、ビスケットの部分の配線は不要です。

下の写真の赤線のように、ビスケットで接続していない部分の`ROW`と`ROW`をハンダめっき線またはダイオードの切れ端などで配線し、ハンダ付けします。

row_connect

### ROWとPro Microとの配線

1列目をPro Microから切り離していなければプレ配線済みなので別途配線する必要はありません。

### COL間の配線

配線済みですので別途配線する必要はありません。

### COLとPro Microとの配線

切り離した基板の`COL`をPro Microと接続する必要があります。

なお、この配線は、ROW間の配線、ダイオードのハンダ付け、キースイッチのハンダ付けの後に実施するとよいです。先に配線してしまうと、これらのハンダ付けがとても大変です。

下の写真は悪い例です。この後にキースイッチをハンダ付けしようとすると配線をかきわけながらハンダごてを当てないといけません。

col_connect

Pro Microと各列を繋げていきますが、1列目はPro Microから切り離していなければプレ配線済みなので配線不要です。

2列目の`COL`のどれか（青丸のどれか）と、Pro Micro中央の`B`と書いてあるスルーホール（青四角）を被覆銅線またはポリウレタン銅線で繋ぎます。

col_connect2

Pro Micro側の配線をする際、配線をスルーホールに押し込むとPro Microとショートする可能性があるので注意してください。

ポリウレタン銅線の太さについては、以下のScrapboxの記事が参考になります。

- [ポリウレタン銅線 - Self-Made Keyboards in Japan](https://scrapbox.io/self-made-kbds-ja/ポリウレタン銅線)

3列目の`COL`のどれか（黄緑色の丸のどれか）と、Pro Micro中央の`C`と書いてあるスルーホール（黄緑色の四角）を被覆銅線またはポリウレタン銅線で繋ぎます。

4列目の`COL`のどれか（オレンジ色の丸のどれか）と、Pro Micro中央の`D`と書いてあるスルーホール（オレンジ色の四角）を被覆銅線またはポリウレタン銅線で繋ぎます。

残りのすべての列も同様に`E`、`F`、`G`…に接続してください。

## ファームウェア

以下のリンク先を参考にして、QMK Firmwareのビルド環境を用意します。

- Windows
  - [QMKビルド環境の構築(Windows Msys2編)](https://gist.github.com/e3w2q/4bc86e531d1c893d3d13af3e9895a94a)
- macOS
  - [セットアップ - QMK Firmware](https://docs.qmk.fm/#/ja/newbs_getting_started?id=macos)
- Linux
  - [セットアップ - QMK Firmware](https://docs.qmk.fm/#/ja/newbs_getting_started?id=linux)

構築中、

```
qmk setup
```

と入力する代わりに

```
qmk setup e3w2q/qmk_firmware --branch e3w2q
```

と入力してください。

または、`qmk setup`した後に、`C:\Users\USER_NAME\qmk_firmware\keyboards`配下に[https://github.com/e3w2q/qmk_firmware/tree/e3w2q/keyboards/e3w2q](https://github.com/e3w2q/qmk_firmware/tree/e3w2q/keyboards/e3w2q)以下をコピーしてもよいです（Windowsの場合）。

### 左サイドにPro Microがある向きで使用する場合

`qmk_firmware/keyboards/e3w2q/te96/rev1/`配下にあるキーマップを書き換えてご利用ください。

デフォルトファームウェアを書き込むには以下を実行します。

```
qmk flash -kb e3w2q/te96/rev1 -km default
```
### 上側にPro Microがある向きで使用する場合

`qmk_firmware/keyboards/e3w2q/te96/rev1_transpose/`配下にあるキーマップを書き換えてご利用ください。

デフォルトファームウェアを書き込むには以下を実行します。

```
qmk flash -kb e3w2q/te96/rev1_transpose -km default
```

### Pro Microが向かい合う形で使用する場合

`qmk_firmware/keyboards/e3w2q/te96/rev1_inverted/`配下にあるキーマップを書き換えてご利用ください。

デフォルトファームウェアを書き込むには以下を実行します。

```
qmk flash -kb e3w2q/te96/rev1_inverted -km default
```
### テスト用のキーマップ

デフォルトキーマップのほかに、テスト用のキーマップを用意しています。

テスト用のキーマップでは、入力したキーの論理的な配置（例えば表から見たときに1行目A列のキーなら「A1」）が入力されます。

[QMK Configuratorのテストモード](https://config.qmk.fm/#/test)を使わずに全キーの入力テストを行う際にご利用ください。

- 左サイドにPro Microがある向きで使用する場合
  ```
  qmk flash -kb e3w2q/te96/rev1 -km test
  ```
- 上側にPro Microがある向きで使用する場合
  ```
  qmk flash -kb e3w2q/te96/rev1_transpose -km test
  ```
- Pro Microが向かい合う形で使用する場合
  ```
  qmk flash -kb e3w2q/te96/rev1_inverted -km test
  ```
### ファームウェアの書き込み

`Detecting USB port, reset your controller now...`と表示されたらPro Microの`GND`と`RST`をピンセットやクリップなどで短絡させると書き込みが始まります。

promicro_reset

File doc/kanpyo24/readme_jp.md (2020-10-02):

# 24 Key Keypad

kanpyo24

<!-- TOC -->

- [24 Key Keypad](#24-key-keypad)
    - [必要なパーツ](#必要なパーツ)
    - [使用する道具、消耗品](#使用する道具消耗品)
    - [ビルドガイド](#ビルドガイド)
        - [Pro Microのもげ防止加工](#pro-microのもげ防止加工)
        - [基板のカット](#基板のカット)
        - [基板側面のヤスリがけ](#基板側面のヤスリがけ)
        - [はんだ付けのイメージトレーニング](#はんだ付けのイメージトレーニング)
        - [ダイオードの取り付け](#ダイオードの取り付け)
        - [Pro Microの取り付け（Pro Micro付属のピンヘッダを使う場合）](#pro-microの取り付けpro-micro付属のピンヘッダを使う場合)
        - [Pro Microの取り付け（コンスルーピンヘッダを使う場合）](#pro-microの取り付けコンスルーピンヘッダを使う場合)
        - [キースイッチの取り付け](#キースイッチの取り付け)
        - [キーキャップの取り付け](#キーキャップの取り付け)
        - [ゴム足の取り付け](#ゴム足の取り付け)
        - [ファームウェアの書き込み](#ファームウェアの書き込み)
    - [トラブルシューティング](#トラブルシューティング)

<!-- /TOC -->

## 必要なパーツ

[te96 パーツリスト](../common/bom_list_jp.md)をご覧ください。

te96基板は1枚使用します。

## 使用する道具、消耗品

[使用する道具、消耗品](../common/tool_guide_jp.md)におすすめの道具類、注意事項等をまとめましたのでご覧ください。

## ビルドガイド

### Pro Microのもげ防止加工

Pro Microにエポキシ接着剤を盛って、簡単にはもげないようにします。

参考1:[ProMicroのモゲ防止ついでにQMK_Firmwareを書き込む - Qiita](https://qiita.com/hdbx/items/2f3e4ddfcadda2a5578e)
参考2:[もげ予防 - Self-Made Keyboards in Japan](https://scrapbox.io/self-made-kbds-ja/%E3%82%82%E3%81%92%E4%BA%88%E9%98%B2)

エポキシ接着剤の2液を混ぜます。

adhesive_prepare

接着剤を付け始める前にMicro USBコネクタを横から見てください。側面に穴が開いています。この穴に接着剤が入ると端子が入らなくなったり、入りにくくなったりします。

usb_side_hole

この穴を避けて、つまようじなどで接着剤を盛っていきます。

promicro_pate

乾くまで置いておきます。

### 基板のカット

下の図のように、ニッパーで切っていきます。ニッパーで表裏に切れ目を入れてから手で折り割ってください。

cut

### 基板側面のヤスリがけ

机に紙ヤスリを置き、その上で基板のバリがある側面をヤスリがけします。粗目だけでも結構きれいになります。お好みで細目までかけてもよいです。

sand_pcb

### はんだ付けのイメージトレーニング

はんだ付けに慣れている方は次の項に進んでください。

全くはんだ付けをしたことがなかったり、数年ぶりにはんだ付けをする場合は、以下の動画が参考になります。

- [はんだ付けの詳細.m2p - YouTube](https://www.youtube.com/watch?v=ZA-ehWjRfYM)

- [チップ抵抗のはんだ付けと、はんだ量の調整（体験用基板を使用） - YouTube](https://www.youtube.com/watch?v=vqKKElJ1vw0)

- [基礎からわかる！自キ入門講座 第8回「自作キーボードのつくりかた #2」 - YouTube](https://www.youtube.com/watch?v=LOC53FeU-QM&t=999)

### ダイオードの取り付け

**基板裏側**にキースイッチの数だけダイオードを取り付けます。

キースイッチの枠が描いてあるほうが基板の表で、ダイオードの印が描いてあるほうが裏です。

まず片方のパッド上にはんだを溶かして盛ります。

diode_position

ダイオードをピンセットでつまみ、基板のシルク印刷の二重線と、表面実装ダイオードの二重線の向きを合わせて、パッドに置きます。

先程パッドに盛ったはんだを溶かしてダイオードの片側をはんだ付けします。

うまくいかない場合は以下の動画をご覧ください。

- [チップ抵抗のはんだ付けと、はんだ量の調整（体験用基板を使用） - YouTube](https://www.youtube.com/watch?v=vqKKElJ1vw0)

diode_attach

表面実装ダイオードのはんだ付けをしていない側をはんだ付けします。

diode_soldered

### Pro Microの取り付け（Pro Micro付属のピンヘッダを使う場合）

**基板表側**のPro Micro設置部分のジグザグスルーホールに、Pro Microに付属している12ピンのピンヘッダの短い側を根本まで差し込みます。

Pro Microを設置できる場所は2箇所ありますが、どちらを使っても構いません。

promicro_pinheader_position

pinheader_attach

スルーホールがジグザグになっているので、少し入れにくくなっています。ゆっくり押し込んでください。

ピンヘッダにPro Microを差し込みます。**Pro Microの裏面（平らなほう）が上になるように、またマイクロUSBが基板端になるように**します。

**向きを間違えるとリカバリーが大変です。表裏、左右をよく確認してください。**

promicro_put

ニッパーでピンヘッダの足のはみ出している部分を切ってから、Pro Microとピンヘッダをハンダ付けします。まず四隅をハンダ付けし、横から見てピンヘッダとの間に隙間があれば押さえながらハンダを温めて浮かないようにします。そのあと、順番に全てハンダ付けします。

promicro_soldered

基板とピンヘッダはジグザグのスルーホールで接触しているため、ハンダ付けはしなくても経験的には大丈夫ですが、接触不良が気になる場合ははんだ付けしてください。

| | 基板とピンヘッダをはんだ付けしない | 基板とピンヘッダをはんだ付けする |
| --- | --- | --- |
| メリット | はんだ付け箇所が減る<br />Pro MicroのMicro USBがモゲたときに交換できる | キーが反応しないとき、接触不良をまず疑うべき箇所が減らせる |
| デメリット | 接触不良により行単位、列単位でキーが反応しない場合がある | はんだ付け箇所が増える<br />Pro MicroのMicro USBがモゲたときに交換が難しい |

### Pro Microの取り付け（コンスルーピンヘッダを使う場合）

**基板表側**のPro Micro設置部分のジグザグではないスルーホール（一番外側の穴を除く）に、別途調達したコンスルーピンヘッダを根本まで差し込みます。

その際、

- コンスルーピンヘッダの金色の窓が遠い側を基板側とし、金色の窓が近い側をProMicro側とする
- 金色の窓の向きを揃える

ようにしてください。

参考: [Helixベータ ビルドガイド](https://github.com/MakotoKurauchi/helix/blob/master/Doc/buildguide_jp.md#pro-micro)

ピンヘッダにPro Microを差し込みます。**Pro Microの裏面（平らなほう）が上になるように、またマイクロUSBが基板端になるように**します。

**向きを間違えるとリカバリーが大変です。表裏、左右をよく確認してください。**

Pro Microを設置できる場所は2箇所ありますが、どちらを使っても構いません。

promicro_conthrough_position

Pro Microとコンスルーピンヘッダをハンダ付けします。まず四隅をハンダ付けし、横から見てコンスルーピンヘッダとの間に隙間があれば押さえながらハンダを温めて浮かないようにします。そのあと、順番に全てハンダ付けします。

基板とコンスルーピンヘッダは接触しているため、ハンダ付けしません。

### キースイッチの取り付け

表側から差し込みます。トッププレート無しでもキースイッチのガタつきがないよう、穴のサイズを小さめにしてあります。キースイッチの足が曲がっている場合はまっすぐにしてから差し込んでください。

裏返してハンダ付けします。

switch_attach

### キーキャップの取り付け

キースイッチにキーキャップをはめます。

kanpyo24

### ゴム足の取り付け

ゴム足を裏面に取り付けます。ソケットやキースイッチに接触する場合はハサミで切ってから取り付けます。

試打してみて、基板のたわみが気になればゴム足を増やしてください。

### ファームウェアの書き込み

以下のリンク先を参考にして、QMK Firmwareのビルド環境を用意します。

- Windows
  - [QMKビルド環境の構築(Windows Msys2編)](https://gist.github.com/e3w2q/4bc86e531d1c893d3d13af3e9895a94a)
- macOS
  - [セットアップ - QMK Firmware](https://docs.qmk.fm/#/ja/newbs_getting_started?id=macos)
- Linux
  - [セットアップ - QMK Firmware](https://docs.qmk.fm/#/ja/newbs_getting_started?id=linux)

構築中、

```
qmk setup
```

と入力する代わりに

```
qmk setup e3w2q/qmk_firmware --branch e3w2q
```

と入力してください。

または、`qmk setup`した後に、`C:\Users\USER_NAME\qmk_firmware\keyboards`配下に[https://github.com/e3w2q/qmk_firmware/tree/e3w2q/keyboards/e3w2q](https://github.com/e3w2q/qmk_firmware/tree/e3w2q/keyboards/e3w2q)以下をコピーしてもよいです。

用意されたキーマップを書き込むには以下を実行します。

```
qmk flash -kb e3w2q/te96/rev1 -km kanpyo24
```

`Detecting USB port, reset your controller now...`と表示されたらPro Microの`GND`と`RST`をピンセットやクリップなどで短絡させると書き込みが始まります。

promicro_reset

[QMK Configuratorのテストモード](https://config.qmk.fm/#/test)でキー入力が行えるかテストしてください。

## トラブルシューティング

- 特定のキーが反応しない
  - キースイッチのハンダ付けが甘い場合があります。キースイッチを押すかわりに、キースイッチの裏面のハンダ2箇所をピンセットでショートさせてみて、入力されるか確認してください。入力される場合は、ハンダ付けし直してください。
- 行、列単位でキーが反応しない
  - Pro Microの足と基板のZigzag穴とがうまく導通していない可能性があります。該当する行または列のPro Microの足を基板のスルーホールの壁に押し付けた状態でキー入力ができるか試してください。この状態でキー入力ができる場合は、きちんと導通するようにPro Microの足が基板の穴の壁に接するようにちょっと曲げてから差し込んでみてください。はんだ付けしてしまうのもよいです。

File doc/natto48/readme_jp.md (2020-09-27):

# Row-Staggered Keyboard

natto48

縦横16mmキーピッチのRow-Staggerdキーボード（横方向にズレたキーボード）の作例です。

<!-- TOC -->

- [Row-Staggered Keyboard](#row-staggered-keyboard)
    - [必要なパーツ](#必要なパーツ)
    - [使用する道具、消耗品](#使用する道具消耗品)
    - [ビルドガイド](#ビルドガイド)
        - [Pro Microのもげ防止加工](#pro-microのもげ防止加工)
        - [基板のカット](#基板のカット)
        - [基板側面のヤスリがけ](#基板側面のヤスリがけ)
        - [はんだ付けのイメージトレーニング](#はんだ付けのイメージトレーニング)
        - [カットした基板の結合](#カットした基板の結合)
        - [隣り合う場所の配線](#隣り合う場所の配線)
        - [ダイオードの取り付け](#ダイオードの取り付け)
        - [Pro Microの取り付け（Pro Micro付属のピンヘッダを使う場合）](#pro-microの取り付けpro-micro付属のピンヘッダを使う場合)
        - [Pro Microの取り付け（コンスルーピンヘッダを使う場合）](#pro-microの取り付けコンスルーピンヘッダを使う場合)
        - [TRRSコネクタの取り付け](#trrsコネクタの取り付け)
        - [キースイッチの取り付け](#キースイッチの取り付け)
        - [離れている場所の配線](#離れている場所の配線)
        - [キーキャップの取り付け](#キーキャップの取り付け)
        - [ゴム足の取り付け](#ゴム足の取り付け)
        - [ファームウェアの書き込み](#ファームウェアの書き込み)
    - [トラブルシューティング](#トラブルシューティング)

<!-- /TOC -->

## 必要なパーツ

[te96 パーツリスト](../common/bom_list_jp.md)をご覧ください。

te96基板は2枚使用します。

## 使用する道具、消耗品

[使用する道具、消耗品](../common/tool_guide_jp.md)におすすめの道具類、注意事項等をまとめましたのでご覧ください。

## ビルドガイド

### Pro Microのもげ防止加工

Pro Microにエポキシ接着剤を盛って、簡単にはもげないようにします。

参考1:[ProMicroのモゲ防止ついでにQMK_Firmwareを書き込む - Qiita](https://qiita.com/hdbx/items/2f3e4ddfcadda2a5578e)
参考2:[もげ予防 - Self-Made Keyboards in Japan](https://scrapbox.io/self-made-kbds-ja/%E3%82%82%E3%81%92%E4%BA%88%E9%98%B2)

エポキシ接着剤の2液を混ぜます。

adhesive_prepare

接着剤を付け始める前にMicro USBコネクタを横から見てください。側面に穴が開いています。この穴に接着剤が入ると端子が入らなくなったり、入りにくくなったりします。

usb_side_hole

この穴を避けて、つまようじなどで接着剤を盛っていきます。

promicro_pate

乾くまで置いておきます。

### 基板のカット

下の図のように、ニッパーで切っていきます。ニッパーで表裏に切れ目を入れてから手で折り割ってください。

Pro Micro部は左右のどちらを残しても動きます。分割キーボードでPro Micro部を左右対称にしたい場合は注意してください。

cut2

下の写真は左手側をカットしたところです。

cut

### 基板側面のヤスリがけ

机に紙ヤスリを置き、その上で基板のバリがある側面をヤスリがけします。粗目だけでも結構きれいになります。お好みで細目までかけてもよいです。

sand_pcb

### はんだ付けのイメージトレーニング

はんだ付けに慣れている方は次の項に進んでください。

全くはんだ付けをしたことがなかったり、数年ぶりにはんだ付けをする場合は、以下の動画が参考になります。

- [はんだ付けの詳細.m2p - YouTube](https://www.youtube.com/watch?v=ZA-ehWjRfYM)

- [チップ抵抗のはんだ付けと、はんだ量の調整（体験用基板を使用） - YouTube](https://www.youtube.com/watch?v=vqKKElJ1vw0)

- [基礎からわかる！自キ入門講座 第8回「自作キーボードのつくりかた #2」 - YouTube](https://www.youtube.com/watch?v=LOC53FeU-QM&t=999)

### カットした基板の結合

基板をビスケットで結合します。ビスケットは3種類あります。下の写真の左から

- 0.5uずらして接続する用

- 0.25uずらして接続する用

- ずらさずに接続する用

です。

縦に連なっている穴は下から

- 16mmキーピッチ用
- 17mmキーピッチ用
- 18mmキーピッチ用
- 19mmキーピッチ用（ずらさずに接続する用のみ）

です。

この作例では、各行は0.25uずつずらして接続し、縦方向のキーピッチは16mmなので、真ん中のビスケットの青枠の穴を使って接続します。

biscuit

ビスケットで接続する前に、**基板を表側にして完成形に並べてからマスキングテープで留めておく**ことを推奨します。これをせずに進めて、表に向けたときに想定したずらし方と逆になっていたことがありました。

基板を裏返してビスケットで接続していきます。ビスケットの数が足りなくなるので、下の写真の青枠のように、各行の両端部のみビスケットを使います。

back2

基板の`ROW`と書かれている穴にビスケットを重ねて、ビンヘッダを差し込みます。

biscuit_and_pinheader

ビスケットからはみ出しているピンヘッダをニッパーでカットして、穴の上からハンダを流し込みます。

### 隣り合う場所の配線

下の写真の青枠のように、ビスケットで接続していない部分の`ROW`と`ROW`をハンダめっき線またはダイオードの切れ端などで配線し、ハンダ付けします。

back3

### ダイオードの取り付け

**基板裏側**にキースイッチの数だけダイオードを取り付けます。

キースイッチの枠が描いてあるほうが基板の表で、ダイオードの印が描いてあるほうが裏です。

まず片方のパッド上にはんだを溶かして盛ります。

diode_position

ダイオードをピンセットでつまみ、基板のシルク印刷の二重線と、表面実装ダイオードの二重線の向きを合わせて、パッドに置きます。

先程パッドに盛ったはんだを溶かしてダイオードの片側をはんだ付けします。

うまくいかない場合は以下の動画をご覧ください。

- [チップ抵抗のはんだ付けと、はんだ量の調整（体験用基板を使用） - YouTube](https://www.youtube.com/watch?v=vqKKElJ1vw0)

diode_attach

表面実装ダイオードのはんだ付けをしていない側をはんだ付けします。

diode_soldered

### Pro Microの取り付け（Pro Micro付属のピンヘッダを使う場合）

**基板表側**のPro Micro設置部分のジグザグスルーホールに、Pro Microに付属している12ピンのピンヘッダの短い側を根本まで差し込みます。

promicro_pinheader_position

pinheader_attach

スルーホールがジグザグになっているので、少し入れにくくなっています。ゆっくり押し込んでください。

ピンヘッダにPro Microを差し込みます。**Pro Microの裏面（平らなほう）が上になるように、またマイクロUSBが基板端になるように**します。

**向きを間違えるとリカバリーが大変です。表裏、左右をよく確認してください。**

promicro_put

ニッパーでピンヘッダの足のはみ出している部分を切ってから、Pro Microとピンヘッダをハンダ付けします。まず四隅をハンダ付けし、横から見てピンヘッダとの間に隙間があれば押さえながらハンダを温めて浮かないようにします。そのあと、順番に全てハンダ付けします。

promicro_soldered

基板とピンヘッダはジグザグのスルーホールで接触しているため、ハンダ付けはしなくても経験的には大丈夫ですが、接触不良が気になる場合ははんだ付けしてください。

| | 基板とピンヘッダをはんだ付けしない | 基板とピンヘッダをはんだ付けする |
| --- | --- | --- |
| メリット | はんだ付け箇所が減る<br />Pro MicroのMicro USBがモゲたときに交換できる | キーが反応しないとき、接触不良をまず疑うべき箇所が減らせる |
| デメリット | 接触不良により行単位、列単位でキーが反応しない場合がある | はんだ付け箇所が増える<br />Pro MicroのMicro USBがモゲたときに交換が難しい |

### Pro Microの取り付け（コンスルーピンヘッダを使う場合）

**基板表側**のPro Micro設置部分のジグザグではないスルーホール（一番外側の穴を除く）に、別途調達したコンスルーピンヘッダを根本まで差し込みます。

その際、

- コンスルーピンヘッダの金色の窓が遠い側を基板側とし、金色の窓が近い側をProMicro側とする
- 金色の窓の向きを揃える

ようにしてください。

参考: [Helixベータ ビルドガイド](https://github.com/MakotoKurauchi/helix/blob/master/Doc/buildguide_jp.md#pro-micro)

ピンヘッダにPro Microを差し込みます。**Pro Microの裏面（平らなほう）が上になるように、またマイクロUSBが基板端になるように**します。

**向きを間違えるとリカバリーが大変です。表裏、左右をよく確認してください。**

promicro_conthrough_position

Pro Microとコンスルーピンヘッダをハンダ付けします。まず四隅をハンダ付けし、横から見てコンスルーピンヘッダとの間に隙間があれば押さえながらハンダを温めて浮かないようにします。そのあと、順番に全てハンダ付けします。

基板とコンスルーピンヘッダは接触しているため、ハンダ付けしません。

### TRRSコネクタの取り付け

表側から差し込みます。まず裏側の一箇所をハンダ付けし、コネクタが基板から浮いていないか確認します。もし浮いていれば、コネクタを押さえながらハンダを温めて溶かし直してください。

trrs_jack

### キースイッチの取り付け

表側から差し込みます。トッププレート無しでもキースイッチのガタつきがないよう、穴のサイズを小さめにしてあります。キースイッチの足が曲がっている場合はまっすぐにしてから差し込んでください。

switch_attach

### 離れている場所の配線

切り離した基板の`COL`をPro Microと接続します。

1行目はPro Microと接続したままなので配線不要です。

2行目の`COL`のどれか（青丸のどれか）と、Pro Micro中央の「1」と書いてあるスルーホール（青四角）を被覆銅線またはポリウレタン銅線で繋ぎます。

Pro Micro側の配線をする際、配線をスルーホールに押し込むとPro Microとショートする可能性があるので注意してください。

3行目の`COL`のどれか（黄緑色の丸のどれか）と、Pro Micro中央の「1」と書いてあるスルーホール（黄緑色の四角）を被覆銅線またはポリウレタン銅線で繋ぎます。

4行目の`COL`のどれか（オレンジ色の丸のどれか）と、Pro Micro中央の「1」と書いてあるスルーホール（オレンジ色の四角）を被覆銅線またはポリウレタン銅線で繋ぎます。

col_connect

### キーキャップの取り付け

キースイッチにキーキャップをはめます。

natto48

### ゴム足の取り付け

ゴム足を裏面に取り付けます。ソケットやキースイッチに接触する場合はハサミで切ってから取り付けます。

試打してみて、基板のたわみが気になればゴム足を増やしてください。

### ファームウェアの書き込み

以下のリンク先を参考にして、QMK Firmwareのビルド環境を用意します。

- Windows
  - [QMKビルド環境の構築(Windows Msys2編)](https://gist.github.com/e3w2q/4bc86e531d1c893d3d13af3e9895a94a)
- macOS
  - [セットアップ - QMK Firmware](https://docs.qmk.fm/#/ja/newbs_getting_started?id=macos)
- Linux
  - [セットアップ - QMK Firmware](https://docs.qmk.fm/#/ja/newbs_getting_started?id=linux)

構築中、

```
qmk setup
```

と入力する代わりに

```
qmk setup e3w2q/qmk_firmware --branch e3w2q
```

と入力してください。

または、`qmk setup`した後に、`C:\Users\USER_NAME\qmk_firmware\keyboards`配下に[https://github.com/e3w2q/qmk_firmware/tree/e3w2q/keyboards/e3w2q](https://github.com/e3w2q/qmk_firmware/tree/e3w2q/keyboards/e3w2q)以下をコピーしてもよいです。

用意されたキーマップを書き込むには以下を実行します。

```
qmk flash -kb e3w2q/te96/rev1_transpose -km natto48
```

`Detecting USB port, reset your controller now...`と表示されたらPro Microの`GND`と`RST`をピンセットやクリップなどで短絡させると書き込みが始まります。

promicro_reset

[QMK Configuratorのテストモード](https://config.qmk.fm/#/test)でキー入力が行えるかテストしてください。

## トラブルシューティング

- 特定のキーが反応しない
  - キースイッチのハンダ付けが甘い場合があります。キースイッチを押すかわりに、キースイッチの裏面のハンダ2箇所をピンセットでショートさせてみて、入力されるか確認してください。入力される場合は、ハンダ付けし直してください。
- 行、列単位でキーが反応しない
  - Pro Microの足と基板のZigzag穴とがうまく導通していない可能性があります。該当する行または列のPro Microの足を基板のスルーホールの壁に押し付けた状態でキー入力ができるか試してください。この状態でキー入力ができる場合は、きちんと導通するようにPro Microの足が基板の穴の壁に接するようにちょっと曲げてから差し込んでみてください。はんだ付けしてしまうのもよいです。

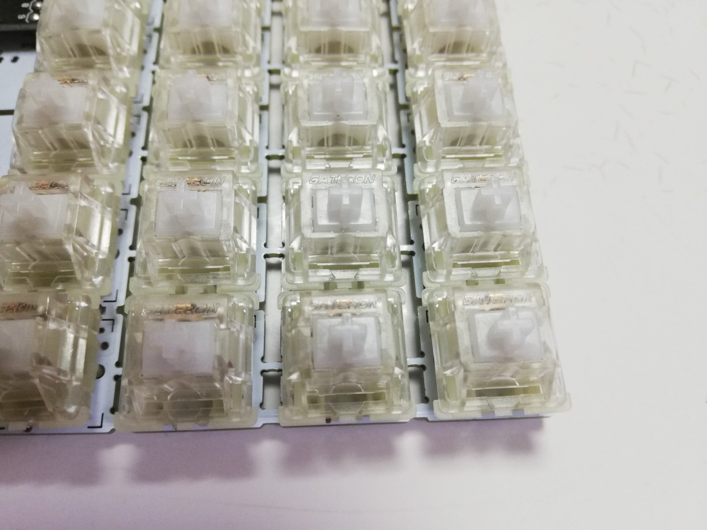
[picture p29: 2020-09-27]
doc/common/image/switch_attach.jpg

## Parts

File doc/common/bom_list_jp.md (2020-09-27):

# te96 パーツリスト

| 名前 | 数 | 備考 | 調達先の例 | 参考価格 |
| --- | --- | --- | --- | --- |
| te96 基板 | 必要枚数 | [入手方法はこちら](../pcb_order_guide/readme_jp.md) | [Elecrow Online store](https://www.elecrow.com/) | 10枚で1,970円($18.80) |
| Pro Micro | 片手につき1個 | | https://talpkeyboard.stores.jp/items/5b24504ba6e6ee7ec60063e3 | 550円 |
| コンスルーピンヘッダ | 片手につき2個 | Pro Microをコンスルーで使いたい場合のみ | https://talpkeyboard.stores.jp/items/5e056626d790db16e2889233 | 220円 |
| 3.5mm4極ミニジャック | 片手につき1個 | 秋月電子型番: MJ-4PP-9<br>マルツ型番: GB-35J-4CW-BM<br>AliExpress: PJ-320A | https://yushakobo.jp/shop/a0800tr-01-1/ | 55円 |
| ダイオード 1N4148W | キー数と同じ  | 表面実装タイプを使用 | https://yushakobo.jp/shop/a0800di-02-100/ | 100個で220円 |
| ピンヘッダ | 接続箇所×2 | ビスケットと基板の接続に使用 | https://akizukidenshi.com/catalog/g/gC-00167/ | 40ピンで35円 |
| 被覆銅線 または ポリウレタン銅線 | | 配線に使用 | https://akizukidenshi.com/catalog/c/csen1/ | 10mで300円 |
| ダイオードの切れ端 または はんだメッキ線 | | 近い場所の配線にあると便利 | https://akizukidenshi.com/catalog/g/gP-13310/ | 40mで900円 |
| 5ピン仕様のキースイッチ MX互換スイッチ または Kailh Chocスイッチ または Kailh Choc V2スイッチ または Kailh Mid-Heightスイッチ | キー数と同じ  | | https://talpkeyboard.stores.jp/?category_id=59cf8860ed05e668db003f5d | 10個で450円～ |
| 16mmキーピッチで利用可能なキーキャップ | キー数と同じ  | [こちらの記事](https://e3w2q.github.io/10/)の16mmキーピッチ以下のもの | https://talpkeyboard.stores.jp/items/5f5444c380933970d139e98c | 2個で150円など |
| クッションゴム | 必要個数 | たわみやすいので多めがよいです | ダイソー クッションゴム 14個入り または すべりどめシート | 110円 |
| Micro USBケーブル | 1本 | 通信ができるもの | ダイソー | 110円 |
| TRRSケーブル | 1本 | AUXオーディオ接続コード | ダイソー | 110円 |

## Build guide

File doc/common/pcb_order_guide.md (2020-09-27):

# PCB Order Guide

## When ordering from ELECROW

https://www.elecrow.com/pcb-manufacturing.html

Use the required Gerber file to upload from the table below.

| Overview | URL | Dimensions  |
| --- | --- | --- |
| PCB | https://github.com/e3w2q/te96-keyboard/blob/master/pcb/te96-gerber.zip?raw=true | 100 x 100mm |

Select your favorite color for resist color.

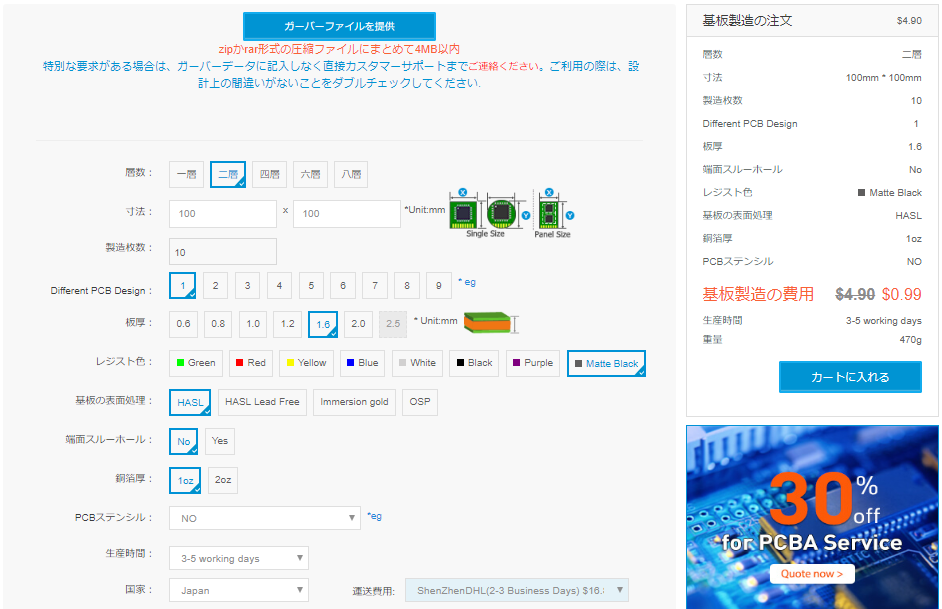
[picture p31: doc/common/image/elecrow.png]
elecrow


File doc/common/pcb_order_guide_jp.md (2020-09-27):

[English](pcb_order_guide.md) / [日本語](pcb_order_guide_jp.md)

# PCBの入手方法

## ELECROWへ発注する場合
[ELECROW基板製造サービス](https://www.elecrow.com/pcb-manufacturing.html)から注文します。

アップロードするガーバーファイルは以下のものを使ってください。

| 概要 | URL | 寸法 |
| ---- | --- | --- |
| 基板 | https://github.com/e3w2q/te96-keyboard/blob/master/pcb/te96-gerber.zip?raw=true | 100×100mm |

100×100mm以下の場合は、5枚も10枚も費用は変わらないので、10枚にするとよいかもしれません。

レジスト色はお好みの色を選択してください。

elecrow

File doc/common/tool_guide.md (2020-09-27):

[English](tool_guide.md) / [日本語](tool_guide_jp.md)

# Tools and consumables

## Examples of procured products

This is a list of items that should be procured. The commentary is summarized below.

| Tools, consumables | Product examples | Examples of suppliers | Reference prices |
| ---- | ---- |  ---- |  ---- |
| Soldering iron | White light dial type temperature control soldering iron FX600 | https://www.amazon.co.jp/dp/B006MQD7M4 | 3,900 yen |
| Replacement iron tip | White light tip 2C type T18-C2 | https://www.amazon.co.jp/dp/B004OR7UBM | 478 yen |
| Soldering iron stand | HAKOKO iron stand 633-01 | https://www.amazon.co.jp/dp/B000TGNWCS | 1,680 yen |
| Solder blotter | Sanhayato Solder Shutaro NEO 45W type HSK-300 | https://www.amazon.co.jp/dp/B01FEV2BPG | 4,918 yen |
| Nippers | Engineer Micro Nipper NS-04 | https://www.amazon.co.jp/dp/B000TGJSWG | 1,414 yen |
| Precision screwdriver +0 | Engineer + Precision screwdriver set 6 DM-20 | https://www.amazon.co.jp/dp/B06XXXVPRY | 807 yen |
| Tester | OHM (Ohm Electric) Digital Multi Tester TDB-401 (04-1891) | https://www.amazon.co.jp/dp/B001TVKWWU | 2,543 yen |
| Solder | goot precision printed circuit board solder SD-62 | https://www.amazon.co.jp/dp/B0029LGAMA | 255 yen |
| Equiposhi adhesive two-component mixed type | Cemedine 5 minutes curing epoxy adhesive High Super 5 P15g set CA-188 | https://www.amazon.co.jp/dp/B0036WHO0S | 566 yen |
| Masking tape | Masking tape for 3M Scotch painting 18mm × 18m M40J-18 | https://www.amazon.co.jp/dp/B005JWNJZM | 95 yen |
| Sandpaper | KAKURI Paper File MIX Set, 12 Sheets | https://www.amazon.co.jp/dp/B01ARIEU0A | 436 yen |
| Total | | | 17,092 yen |

## Explanation

### Soldering iron

I do not recommend soldering irons from 100 yen shops.

From [WEBはんだ付け講座 はじめに・・](https://noseseiki.com/kisokouza/01.html)

> Currently, in Japan, soldering irons with no temperature control function are used by the majority of people who solder. These soldering irons have a too high tip temperature of 450-550 ° C. For this reason, most products soldered with this soldering iron will be overheated.

If you don't have much soldering experience or have done it a long time ago, we strongly recommend that you prepare one with temperature control.

### Replacement tip

Since the conical shape attached to the soldering iron from the beginning hits the target and the point, it is difficult for heat to be transmitted, and solder may be placed due to insufficient heating, so replace it with the 2C tip and heat on the surface It is easy to do it if you can.

### Soldering iron stand

Necessary for safely placing the soldering iron.

### Solder blotter or wire

It is good to have it because it is not necessary when soldering fails.

### Nipper

It is used for cutting board / biscuits, cutting diode legs / pin headers.

Nippers are not recommended for 100 yen shops for the following reasons.

- Sharpness is not so good, and it is difficult to cut the diode feet and pin header.
- Since the blade is not a sword, it cannot be cut

### Tester

Necessary for problem isolation when keys cannot be entered.

All you need is a conduction mode.

### Electronic work solder

Leaded type is easy to work with.

Since there are no particularly small parts used for SU120, even a 1mm one can work well, but 0.8mm seems to melt the solder easily.

### Epoxy adhesive two-component mixed type

Used for Pro Micro baldness prevention processing.

### Masking tape

It is used to fix parts when turning the board over by soldering.

## Web page for reference (Japanese)

- [Helix キーボードキットの製作に必要な工具メモ - GitHub](https://gist.github.com/mtei/6957107a676ddfa85bde0ae41f8fa849)
- [自作キーボードを作るために必要なもの - 自作キーボード温泉街の歩き方](https://salicylic-acid3.hatenablog.com/entry/2018/11/24/自作キーボードを作るために必要なもの)
- [自作キーボードの組み立てに使っている工具 | yfuku docs](https://yfuku.com/blog/keyboard/keybord_build_tool/)
- [elephant42 の組み立てかた#工具の準備 · illness072/elephant42](https://github.com/illness072/elephant42/blob/master/docs/build-guide.md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)
- [基礎からわかる！自キ入門講座 第8回「自作キーボードのつくりかた #2」 - YouTube](https://salicylic-acid3.hatenablog.com/entry/2018/11/24/自作キーボードを作るために必要なもの)

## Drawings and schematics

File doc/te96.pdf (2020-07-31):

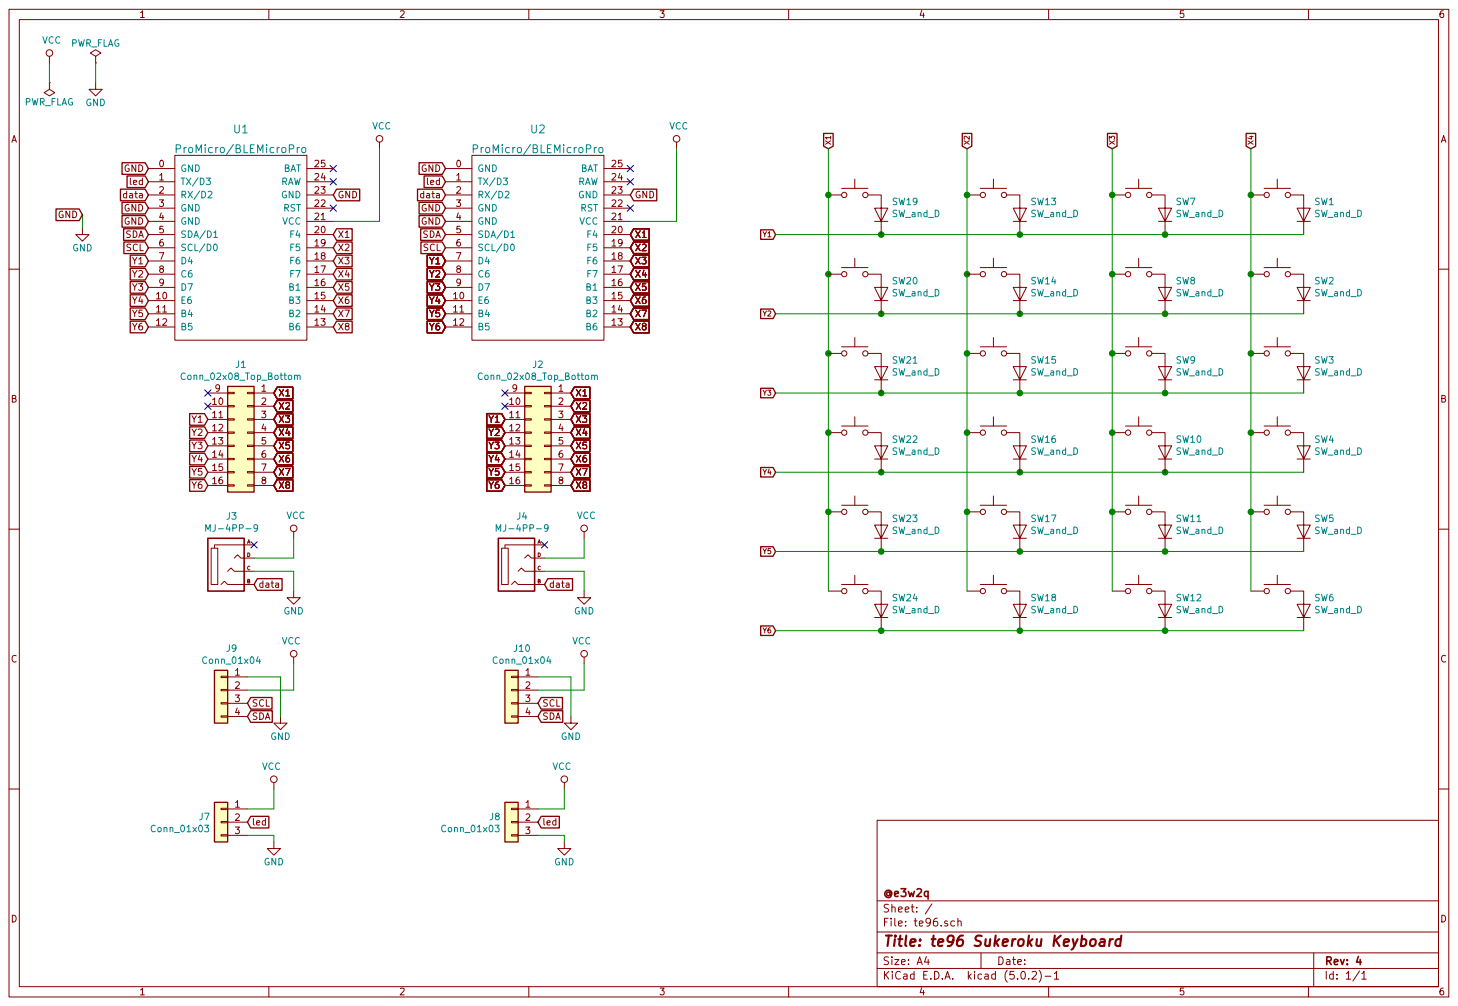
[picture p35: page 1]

Id: 1/1 Title: te96 Sukeroku Keyboard

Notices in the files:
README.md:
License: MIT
